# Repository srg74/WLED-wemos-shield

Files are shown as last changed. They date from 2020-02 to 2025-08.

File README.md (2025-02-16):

# WLED wemos shield with [plug-in add-ons](https://github.com/srg74/WLED-wemos-shield/tree/master/resources/Add-ons)








I appreciate your support for my project! 

## Wi-Fi LED shield based on Wemos D1 Mini original or clones, Wemos ESP32 D1 mini, for WLED firmware

- Detailed assembly and option information is [here](https://github.com/srg74/WLED-wemos-shield/wiki)

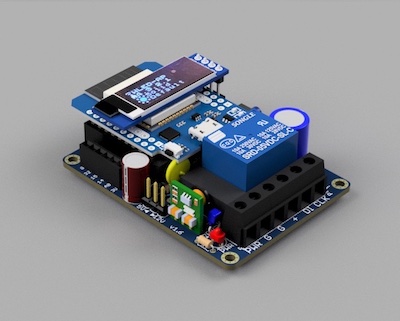
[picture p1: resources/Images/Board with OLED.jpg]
Shield (https://github.com/srg74/WLED-wemos-shield/wiki)


### For changes in design please see [changelog.md](https://github.com/srg74/WLED-wemos-shield/blob/master/Changelog.md)

## PCB ordering

- [Ordering](https://www.pcbway.com/project/shareproject/WLED_wemos_shield.html) - $5 for 10 PCBs very good quality.
- [Sign in and save](https://www.pcbway.com/setinvite.aspx?inviteid=83580) - Helping me to save some money for development.
- [Ready to use fully assembled shield on Tindie](https://www.tindie.com/products/22307/)

## Wi-Fi LED controller with following features

- Very easy to configure for your project;
- Easy to solder components;
- Level shifter for reliable data signal;
- Solder jumpers for flexible configuration;
- Power selector (e.g 5VDC or 12/24VDC);
- Can be configured for 1 (data) wire and 2 (data, clock) wire addressable LED strips;
- Analog and Digital input for sound reactive compatability;
- Button option on board;
- Relay for power saving feature (without disconnecting power from LED strip it still consumes current even if none of the LEDs are lit);
- Auxilary power for additional relay or other 5VDC powered devices;
- I2C connector for OLED display or other devices that might be integrated in a feature;
- I2S connectivity for ESP32 boards;
- Optional IR reciever;
- Optional Dallas temperature sensor;
- Optional I2C sensors;
- Components on board for 4 or 3 pin PWM fan circuit.

## Firmware

### Ready to use bin files

- [@Aircookie repo firmware builds](https://github.com/srg74/WLED-wemos-shield/tree/master/resources/Firmware/%40Aircoookie) - Original WLED repository bin files for various configurations
- [@blazoncek fork firmware builds](https://github.com/srg74/WLED-wemos-shield/tree/master/resources/Firmware/%40blazoncek) - Custom development bin files for various configurations
- [@Atuline fork firmware builds](https://github.com/srg74/WLED-wemos-shield/tree/master/resources/Firmware/%40Atuline) - Sound reactive bin files for various configurations
- [@Moonmodules fork firmware builds](https://github.com/srg74/WLED-wemos-shield/tree/master/resources/Firmware/%40MoonModules) - Advanced sound reactive bin files for various configurations

### Resources used for bin files compiling

- [WLED repository](https://github.com/wled-dev/WLED) - Aircoookie original WLED repository
- [Atuline WLED fork](https://github.com/atuline/WLED) - Audio reactive WLED fork
- [MoonModules WLED fork](https://github.com/MoonModules/WLED) - Enhenced Audio reactive WLED fork 
- [WLED dev repository](https://github.com/blazoncek/WLED) - Blazoncek advanced development WLED fork

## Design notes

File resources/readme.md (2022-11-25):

# PCB ordering

- [Ordering](https://www.pcbway.com/project/shareproject/WLED_wemos_shield.html) - $5 for 10 PCBs in no time :) Parts list in BOM.

## Shield PCBs and schematic

## PCB

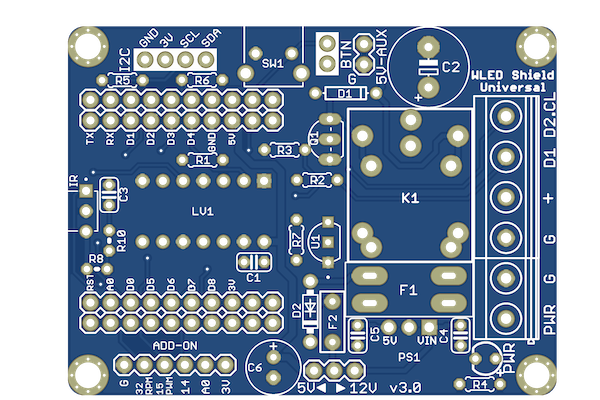
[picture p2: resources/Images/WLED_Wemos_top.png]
PCB


## Schematic

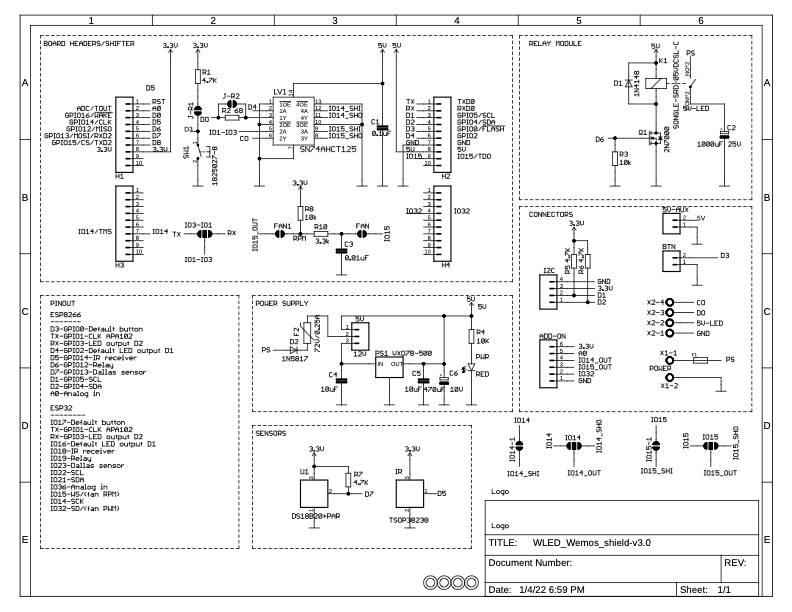
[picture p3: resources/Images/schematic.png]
Schematic


## Parts

- [BOM](https://github.com/srg74/WLED-wemos-shield/blob/master/resources/BOM/BOM_v2.1.pdf) - Bill of materials in PDF format.
- [BOM](https://github.com/srg74/WLED-wemos-shield/blob/master/resources/BOM/BOM_v2.1.xlsx) - Bill of materials in XLSX format.
- [BOM](https://github.com/srg74/WLED-wemos-shield/blob/master/resources/BOM/BOM_v2.1_LCSC.xlsx) - Bill of materials for ordering at LCSC.com.
- [Digikey part list](https://github.com/srg74/WLED-wemos-shield/blob/master/resources/BOM/BOM_Digi-key_v2.1.csv) - BOM file that you can upload to Digikey website for order.

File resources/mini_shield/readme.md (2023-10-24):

# WLED Wemos mini shield

- [ESP8266 and ESP32 firmware](https://github.com/srg74/WLED-wemos-shield/tree/master/resources/Firmware/WLED_wemos_shield) -  Aircookie official.
- [ESP8266 and ESP32 firmware](https://github.com/srg74/WLED-wemos-shield/tree/master/resources/Firmware/Sound_reactive) - Sound reactive WLED repository from [Andrew Tuline](https://github.com/atuline/WLED).
- [ESP8266 and ESP32 firmware](https://github.com/srg74/WLED-wemos-shield/tree/master/resources/experimental) - Advanced experimental WLED repository from [Blazoncek](https://github.com/blazoncek/WLED).
- [Connection guide](https://github.com/srg74/WLED-wemos-shield/blob/master/resources/mini_shield/mini_connection_guide_v1.2.pdf) - Connection guide for WS281X strips and clocked APA102.
- [Pinout for standart mini shield](https://github.com/srg74/WLED-wemos-shield/blob/master/resources/mini_shield/mini_shield_v1.2_pinout.pdf)
- [Pinout for AUX mini shield](https://github.com/srg74/WLED-wemos-shield/blob/master/resources/mini_shield/aux-shield.md)
- [Recommended 3D printed enclosure](https://www.thingiverse.com/thing:4965917) - design by @HarryBaas

***
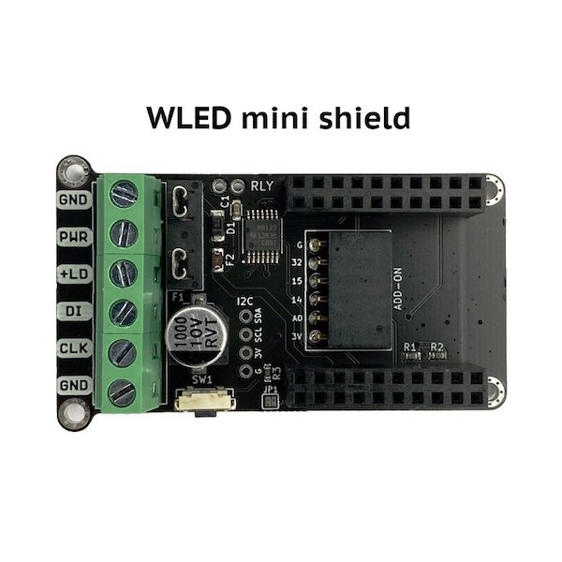
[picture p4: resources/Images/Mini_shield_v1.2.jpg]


***
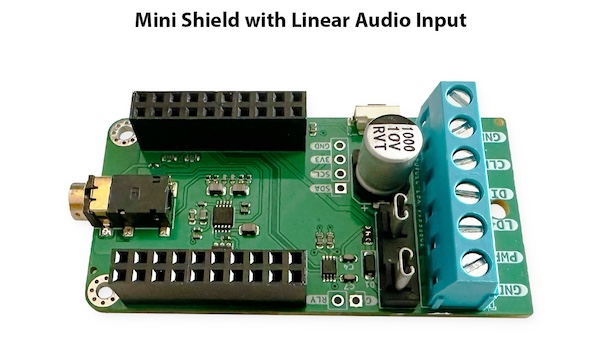
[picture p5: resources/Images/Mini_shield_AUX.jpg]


- [Pinout for AUX mini shield](https://github.com/srg74/WLED-wemos-shield/blob/master/resources/mini_shield/aux-shield.md)

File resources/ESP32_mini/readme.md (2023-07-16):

# ESP32 mini dev board

[All docs moved to](https://github.com/srg74/ESP32-mini-SerKo) separate GitHub repo

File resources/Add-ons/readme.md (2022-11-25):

# Available add-ons

## [Linear audio input add-on plug-in board](#1linear-audio-input-add-on-plug-in-board)

## [Digital microphone ICS-43434 add-on plug-in board](#2digital-microphone-ics-43434-add-on-plug-in-board)

## [Digital input/output screw terminal add-on plug-in board](#3-digital-inputoutput-screw-terminal-add-on-plug-in-board)

### [1]Linear audio input add-on plug-in board

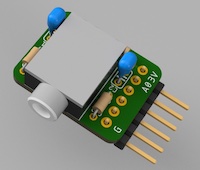
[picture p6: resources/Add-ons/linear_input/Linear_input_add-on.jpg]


- [Order PCB](https://www.pcbway.com/project/shareproject/Audio_input_for_shield_v1_5.html)
- [Schematic](https://github.com/srg74/WLED-wemos-shield/blob/master/resources/Add-ons/linear_input/Sound_reactive_add-on.pdf)
- [Parts](https://github.com/srg74/WLED-wemos-shield/blob/master/resources/Add-ons/linear_input/BOM.pdf)
- [All credits and references for circuits. Thanks to atuline and his team for the Sound reactive fork](https://github.com/atuline/WLED)

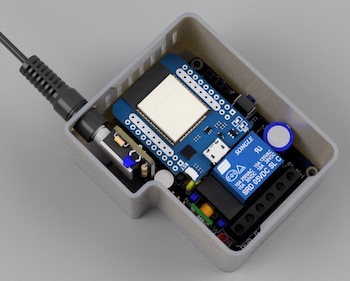
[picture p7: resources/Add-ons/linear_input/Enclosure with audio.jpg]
Linear in


### [2]Digital microphone ICS-43434 add-on plug-in board

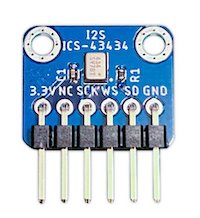
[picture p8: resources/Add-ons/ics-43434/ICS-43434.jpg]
ICS43434




- [Schematic](https://github.com/srg74/WLED-wemos-shield/blob/master/resources/Add-ons/ics-43434/ics43434_shield.jpg)

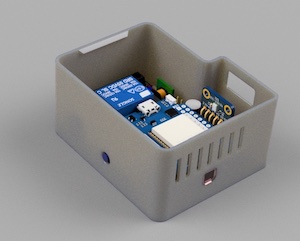
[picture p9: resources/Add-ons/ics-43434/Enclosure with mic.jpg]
Enclosure with mic


### [3] Digital input/output screw terminal add-on plug-in board

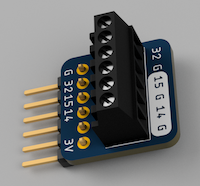
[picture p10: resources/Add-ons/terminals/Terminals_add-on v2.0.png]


- [Order PCB](https://www.pcbway.com/project/shareproject/Audio_input_for_shield_v1_5.html)
- [Schematic](https://github.com/srg74/WLED-wemos-shield/blob/master/resources/Add-ons/terminals/Terminals_add-on.pdf)
- [Parts](https://github.com/srg74/WLED-wemos-shield/blob/master/resources/Add-ons/terminals/BOM.xlsx)

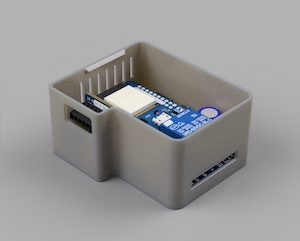
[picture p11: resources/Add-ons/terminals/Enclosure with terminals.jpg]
Screw terminals


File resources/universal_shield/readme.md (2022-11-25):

# Universal shield black v3.0

- [Shield pinout](https://github.com/srg74/WLED-wemos-shield/blob/master/resources/Images/wiki/Wemos_shield_pinout.pdf)

## Shield PCBs and schematic

## PCB

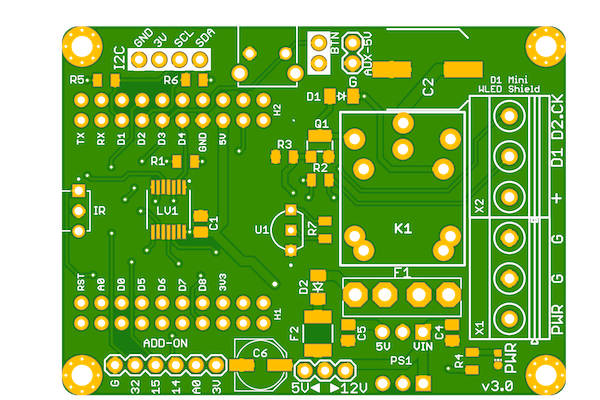
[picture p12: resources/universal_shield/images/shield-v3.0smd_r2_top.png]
PCB top


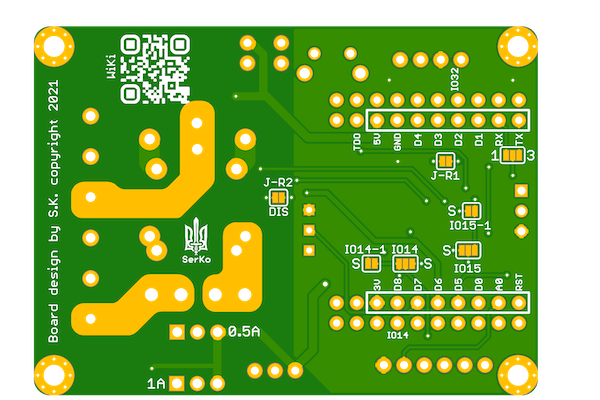
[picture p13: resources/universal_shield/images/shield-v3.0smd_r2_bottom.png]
PCB bottom


## Solder jumpers

- By default shield is preconfigured for use with digital microphone(IO14 and IO15 not shifted);
- Jumpers have to be soldered according to chosen configuration:
- IO1-IO3 - Lets you choose D2 output, GPIO1 or GPIO3;
- IO15 (ESP32 only)- Lets you choose if your output 15 is shifted or not (side marked "S" is shifted);
- IO15-1 (ESP32 only) - Must be soldered if output 15 is shifted;
- IO14 (ESP32 only) - Lets you choose if your output 14 is shifted or not (side marked "S" is shifted);
- IO14-1 (ESP32 only) - Must be soldered if  output 14 is shifted;
- J-R2 - If soldered, bypasses resistor R2;
- J-R1 - Soldered if resistor R1 must be used;

## Schematic

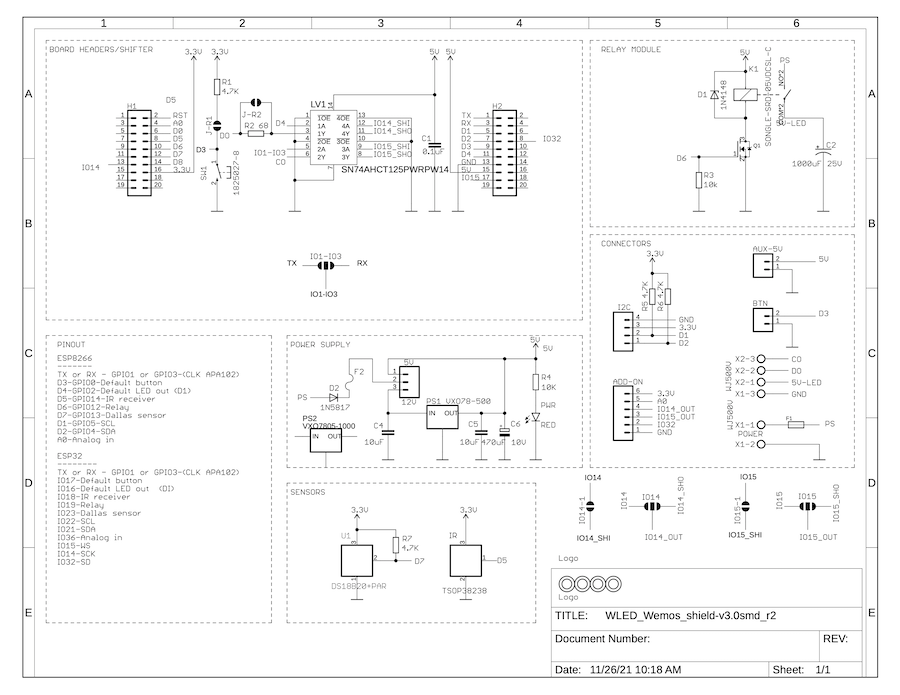
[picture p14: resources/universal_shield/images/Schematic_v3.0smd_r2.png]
Schematic


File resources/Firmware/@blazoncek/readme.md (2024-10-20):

# Development fork @blazoncek

- [v0.15.0-b6 builds](https://github.com/srg74/WLED-wemos-shield/tree/master/resources/Firmware/@blazoncek/latest) - v0.15.0-b6 build 2410200

```text
# Example for a build
[env:esp32_Dallas_sensor_PWM_fan_display_rotary_ambient_light_sensor_sound_mods]
board = esp32dev
platform = espressif32@3.5
upload_speed = 460800
monitor_speed = 115200
;upload_protocol = espota
# exchange for your WLED IP
;upload_port = "10.0.0.94"
build_unflags = ${common.build_unflags}
build_flags = ${common.build_flags_esp32}
  -D WLED_DISABLE_BLYNK
  -D WLED_DISABLE_CRONIXIE
  -D WLED_DISABLE_HUESYNC
  -D WLED_DISABLE_LOXONE
# Enable Ethernet shield
;  -D WLED_USE_ETHERNET
# Pins assigment and pixel count
  -D BTNPIN=0
  -D LEDPIN=2 # Single pin
;  -D DATA_PINS=1,2 # Multiple pins
;  -D PIXEL_COUNTS=150,150,150,150 # Pixel count assigment
  -D IRPIN=-1
  -D RLYPIN=16
# User mods
  # Dallas temperature sensor mod
  -D USERMOD_DALLASTEMPERATURE
  -D TEMPERATURE_PIN=4
  # Display mod
  # I2C display section
  -D USERMOD_FOUR_LINE_DISPLAY
  -D USE_ALT_DISPlAY
  -D FLD_PIN_SCL=22
  -D FLD_PIN_SDA=21
  -D FLD_TYPE=SH1106
;  -D FLD_TYPE=SSD1306
  # SPI display section
  ; -DFLD_SPI_DEFAULT
  ; -D FLD_TYPE=SSD1306_SPI64
  ; -D FLD_PIN_CLOCKSPI=14
  ; -D FLD_PIN_DATASPI=13
  ; -D FLD_PIN_DC=26
  ; -D FLD_PIN_CS=15
  ; -D FLD_PIN_RESET=27
  # Rotary encoder mod
  -D USERMOD_ROTARY_ENCODER_UI
  -D ENCODER_DT_PIN=18
  -D ENCODER_CLK_PIN=19
  -D ENCODER_SW_PIN=17
  # Multirelay mod
  ; -D USERMOD_MULTI_RELAY  # 12, 23, 22 & 21
  # PWM Fan mod
  -D USERMOD_PWM_FAN
  -D PWM_PIN=32
  -D TACHO_PIN=33
  # Ambient light sensor BH1750
  -D USERMOD_BH1750
  -D USERMOD_BH1750_FIRST_MEASUREMENT_AT=30000
  -D USERMOD_BH1750_MAX_MEASUREMENT_INTERVAL=60000
;  -D USERMOD_BH1750_MIN_MEASUREMENT_INTERVAL=10000
;  -D USERMOD_BH1750_OFFSET_VALUE=2
  # Sound reactive usermod
  -D USERMOD_AUDIOREACTIVE
;  -D WLED_DEBUG
  -UWLED_USE_MY_CONFIG
lib_deps = ${esp32.lib_deps}
  U8g2@~2.32.15 # Uncoment for display mod
  paulstoffregen/OneWire@~2.3.6 # Uncoment for temperature mod
  claws/BH1750 @ ^1.3.0 # Uncoment for light sensor mod
  https://github.com/blazoncek/arduinoFFT.git
board_build.partitions = ${esp32.default_partitions}
```

## 🔴 Please, test latest firmware and report any issue to WLED Discord. Help highly anticipated and appreciated! 🔴

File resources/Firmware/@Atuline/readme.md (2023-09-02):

# Audio reactive fork firmware @Atuline

[ESP32 Audio reactive firmware](https://github.com/srg74/WLED-wemos-shield/tree/master/resources/Firmware/@Atuline/latest) - 0.13.4 build 2309020

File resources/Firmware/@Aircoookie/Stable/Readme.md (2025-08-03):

# WLED PlatformIO Builds

This project supports multiple hardware targets and configurations. Below is a summary of the actively defined builds:

---

## Shields Builds

### esp01_1m_full_shield

- **Target:** ESP01 shield (1MB flash)
- **Features:** Minimal build for ESP01 shield, disables several features to fit in 1MB.

### esp8266_mini_shield_minimum

- **Target:** D1 mini board (4MB)
- **Features:** Minimal build for mini shield, disables some features for space.

### esp32_mini_shield_minimum_4mb

- **Target:** ESP32 mini board (4MB)
- **Features:** Minimal build for ESP32 mini shield, disables some features for space.

### esp32_mini_shield_minimum_16mb

- **Target:** ESP32 mini board (16MB)
- **Features:** Minimal build for ESP32 mini shield, disables some features for space.

### esp32_mini_shield_aux_16mb

- **Target:** ESP32 mini board (16MB)
- **Features:** Auxiliary build, includes audio reactive usermod.

### esp8266_universal_shield_minimum

- **Target:** D1 mini board (universal shield)
- **Features:** Minimal build for universal shield, disables some features for space.

### esp32_universal_shield_minimum_4mb

- **Target:** ESP32 mini board (4MB, universal shield)
- **Features:** Minimal build for universal shield, disables some features for space.

### esp32_universal_shield_minimum_16mb

- **Target:** ESP32 mini board (16MB, universal shield)
- **Features:** Minimal build for universal shield, disables some features for space.

### esp32_universal_shield_usermods_4mb

- **Target:** ESP32 board (4MB, universal shield)
- **Features:** Usermods build, includes temperature, four_line_display_ALT, rotary encoder, audioreactive.

### esp32_universal_shield_usermods_16mb

- **Target:** ESP32 board (16MB, universal shield)
- **Features:** Usermods build, includes temperature, four_line_display_ALT, rotary encoder, audioreactive.

---

## ESP32 Dev Board Builds

### esp32_devb_Dallas_sensor_PWM_fan_mods_4mb

- **Target:** ESP32 dev board (4MB)
- **Features:** Dallas temperature sensor, PWM fan usermods.

### esp32_devb_Dallas_sensor_PWM_fan_mods_16mb

- **Target:** ESP32 dev board (16MB)
- **Features:** Dallas temperature sensor, PWM fan usermods.

### esp32_devb_SHT_sensor_PWM_fan_mods_16mb

- **Target:** ESP32 dev board (16MB)
- **Features:** SHT temperature sensor, PWM fan usermods.

### esp32_devb_4ch_fan_display_rotary_relays

- **Target:** ESP32 dev board
- **Features:** PWM fan, temperature, four_line_display_ALT, rotary encoder, multi relay usermods.

---

## ESP32-pico-D4 Board Builds

### esp32_pico_board

- **Target:** ESP32-pico-D4 board
- **Features:** Audio reactive usermod.

### esp32_pico_v3_02

- **Target:** ESP32-pico-v3-02 board
- **Features:** 8MB flash, disables brownout detector.

---

## Manufacturer Hacked Controllers

### sp501e_2mb

- **Target:** ESP8266 2MB board (SP501E)
- **Features:** Disables several features for space, supports up to 3 virtual busses.

### sp511e_2mb

- **Target:** ESP8266 2MB board (SP511E)
- **Features:** Disables several features for space, supports up to 3 virtual busses.

---

## Users Requested/Test Builds

### esp8266_debug

- **Target:** ESP8266 (D1 mini)
- **Features:** Debug build, disables some features, enables debug output.

### esp32_debug

- **Target:** ESP32 dev board
- **Features:** Debug build, includes audioreactive usermod, enables debug output.

### esp8266_dmx

- **Target:** ESP8266 (D1 mini)
- **Features:** DMX support enabled.

### esp8266_PIRmod

- **Target:** ESP8266 (D1 mini)
- **Features:** PIR switch usermod.

### esp8266_staircase_mod

- **Target:** ESP8266 (D1 mini)
- **Features:** Animated staircase usermod, disables several features.

### esp8266_display_rotary

- **Target:** ESP8266 (D1 mini)
- **Features:** Four line display and rotary encoder usermods.

### esp8266_dallas_mod

- **Target:** ESP8266 (D1 mini)
- **Features:** Dallas temperature sensor usermod, disables several features.

### esp32_PIRmod

- **Target:** ESP32 dev board
- **Features:** PIR switch usermod.

### esp32_staircase_mod

- **Target:** ESP32 dev board
- **Features:** Animated staircase usermod.

### esp32_ethernet

- **Target:** ESP32 dev board
- **Features:** Ethernet support enabled, disables several features.

### esp32_dmx

- **Target:** ESP32 dev board
- **Features:** DMX support enabled.

### esp32_bme280

- **Target:** ESP32 dev board
- **Features:** BME280 sensor and four line display usermods.

### esp32_display_rotary_encoder_battery_stat

- **Target:** ESP32 dev board
- **Features:** Four line display and rotary encoder usermods.

### esp32s2_saola_1

- **Target:** ESP32-S2 Saola board
- **Features:** Experimental build for ESP32-S2.

### esp32s3dev_8MB

- **Target:** ESP32-S3 dev board (8MB)
- **Features:** Audio reactive usermod, new FFT, S3-specific settings.

### esp32_stamp5_c3

- **Target:** ESP32-C3 devkit
- **Features:** Audio reactive usermod, SQUELCH and GAIN settings for ICS-4343x.

---

## Notes

- Each build can be selected by specifying the corresponding environment in PlatformIO.
- For custom builds, refer to the comments and usermod documentation for additional configuration options.

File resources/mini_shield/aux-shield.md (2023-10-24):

# AUX mini shield configuration

```    -D LEDPIN=16 #  2nd output or LED CLK GPIO 17
    -D RLYPIN=-1 # If relay connected GPIO 19
    -D BTNPIN=5 # Button GPIO 5
    -D IRPIN=-1 # IR pin disabled
    -D SR_DMTYPE=4 # Type of audio processor
    -D MCLK_PIN=0 # Clock pin
    -D I2S_SDPIN=26
    -D I2S_WSPIN=25
    -D I2S_CKPIN=27
```

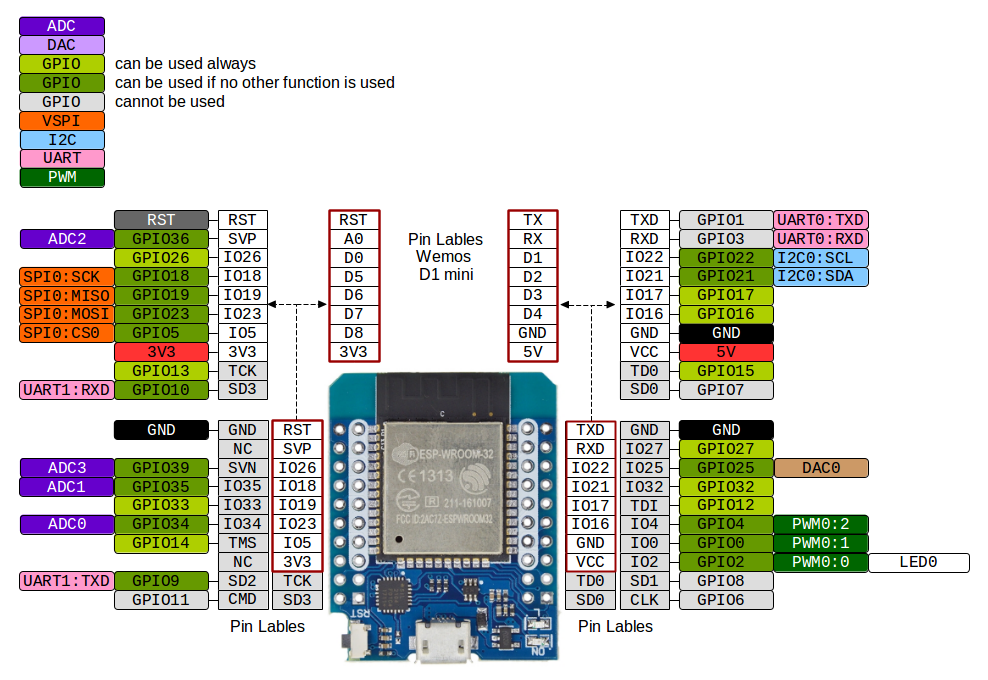
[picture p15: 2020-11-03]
resources/Images/MH-ET_LIVE_D1_mini_ESP32_pinout.png

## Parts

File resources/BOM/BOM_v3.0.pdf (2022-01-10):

### WLED_Wemos_shield_Digikey

WLED Wemos shield BOM

Name | Value | Manufacturer | Digikey | MPN | QTY
R3, R4, R8 | 10kOhm | Stackpole Electronics Inc | S10KQCT-ND | CFM14JT10K0 | 3
R1, R5, R6, R7 | 4.7kOhm | Stackpole Electronics Inc | S4.7KQCT-ND | CFM14JT4K70 | 4
R2 | 56Ohm | Stackpole Electronics Inc | S56QCT-ND | CFM14JT56R0 | 1
R10 | 3.3kOhm | Stackpole Electronics Inc | S3.3KQCT-ND | CFM14JT3K30 | 1
C1 | 0.1uF | Kemet | 399-4151-ND | C315C104M5U5TA | 1
C4, C5 | 10uF | TDK Corporation | 445-8262-ND | FK11X7R1E106M | 2
C3 | 0.01uF | Hemet | 399-C316C103M5U5TA-ND | C316C103M5U5TA | 1
C6 | 470uF 10V | Würth Elektronik | 732-8708-1-ND | 860010273011 | 1
C2 | 1000uF 25V | Nichicon | 493-1065-ND | UVR1E102MPD | 1
Q1 | 2N7000 | ON Semiconductor | 2N7000FS-ND | 2N7000 | 1
D1 | 1N4148 | Vishay Diodes | 1N4148-P-TAPGICT-ND | 1N4148-P-TAP | 1
D2 | 1N5817 | Micro Commercial Co | 1N5817-TPCT-ND | 1N5817-TP | 1
U1 | DS18B20 | Maxim Integrated | DS18B20+-ND | DS18B20+ | 1
F1 | 3568 | Keystone Electronics | 36-3568-ND | 3568 | 1
F2 | 16V 900mA | Littelfuse Inc. | RUSBF090-2HFCT-ND | RUSBF090-2 | 1
LV1 | SN74AHCT125 | Texas Instruments | 296-4655-5-ND | SN74AHCT125N | 1
K1 | SRD-05VDCSL-C | Songle | Amazon, Aliexpress | SRD-05VDCSL-C | 1
K1 alternate | ORWH-SH-105D1F,000 | TE Connectivity Potter | PB2032-ND | ORWH-SH-105D1F,000 | 1
PS1 (jumper select) | VXO7805-500 | CUI Inc. | 102-4249-ND | VXO7805-500 | 1
X1 | TERM BLK 2P SIDE ENT 5.08MM PCB | Molex | WM4393-ND | 398800302 | 1
X2 | TERM BLK 4P SIDE ENT 5.08MM PCB | Molex | WM13972-ND | 398800304 | 1
H1, H2 | CONN HDR 20POS 0.1 GOLD PCB | Sullins Connector Solutions | S6106-ND | PPPC102LFBN-RC | 2
I2C | CONN HDR 4POS 0.1 GOLD PCB | Sullins Connector Solutions | S7037-ND | PPPC041LFBN-RC | 1
SOUND | CONN HDR 6POS 0.1 GOLD PCB | Sullins Connector Solutions | S7039-ND | PPPC061LFBN-RC | 1
Headers | CONN HEADER VERT 20POS 2.54MM | Harwin Inc. | 952-3306-ND | M20-9992045 | 1
Jumper | CONN JUMPER SHORTING GOLD | Sullins Connector Solutions | S9001-ND | SPC02SYAN | 1
SW1 | SWITCH TACTILE | TE Connectivity | 450-1657-ND | 1825027-8 | 1
IR | SENSOR REMOTE REC 38.0KHZ 45M | Vishay Semiconductor | TSOP38238 | TSOP38238 | 1
FUSE | Mini fuse is depend on current rating of your setup. Kit https://www.amazon.com/CrocSee-250-Pieces-Assortment-Replacement/dp/B0895PV8S2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 (https://www.amazon.com/CrocSee-250-Pieces-Assortment-Replacement/dp/B0895PV8S2)
Power indicator LED | https://www.amazon.com/1-8mm-2mm-Round-Top-Red/dp/B017TR9ZDY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

1

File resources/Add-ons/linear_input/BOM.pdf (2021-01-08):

### WLED_Wemos_add_on_Digikey

WLED Wemos shield BOM

Name | Value | Manufacturer | Digikey | MPN | QTY
R1, R2 | 680Ohm | Stackpole Electronics Inc | S680QCT-ND | CFM14JT680R | 2
R3, R4 | 1mOhm | Stackpole Electronics Inc | S1MQCT-ND | CFM14JT1M00 | 2
C1, C2 | 0.1uF | Kemet | 399-4151-ND | C315C104M5U5TA | 2
Audio jack | 3.50mm - Headphone Phone Jack | Harwin Inc. | CP1-3513N-ND | SJ1-3513N | 1
Connector | Header Right Angle 6 pos | Harwin Inc. | 952-2247-ND | M20-9960645 | 1

1

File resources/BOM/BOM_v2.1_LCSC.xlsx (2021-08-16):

WLED_Wemos_shield_LCSC.com
WLED Wemos shield BOM
Name | Value | Manufacturer | LCSC | MPN | QTY
R3, R4 | 10kOhm | UNI-ROYAL | C58673 | MFR0W8F1002A50 | 2
R1, R5, R6, R7 | 4.7kOhm | UNI-ROYAL | C58678 | MFR0W8F4701A50 | 4
R2 | 36Ohm | VO | C337034 | CR1/8W ±5% 36Ω STB5 | 1
C1 | 0.1uF | FH | C154503 | CT4-0805Y104M500F1 | 1
C4, C5 | 10uF | Murata | C162684 | RDEC71H106K3K1H03B | 2
C6 | 470uF 10V | Samwha Capacitor | C160618 | RD1A477M6L011PC | 1
C2 | 1000uF 25V | CX | C44595 | KM108M025G20RR0VH2FP0 | 1
Q1 | 2N7000 | Changjiang Electronics Tech | C9114 | 2N7000 | 1
D1 | 1N4148 | ST(Semtech) | C14538 | 1N4148 | 1
D2 | 1N5817 | Diodes incorporated | C507852 | 1N5817-T | 1
U1 | DS18B20 | UMW | C376006 | DS18B20 | 1
F1 | 3568 | Keystone Electronics | 36-3568-ND | 3568 | 1
F2 | 30V 0.5A | TECHFUSE | C2833617 | R30-050 | 1
LV1 | SN74AHCT125 | Texas Instruments | C354152 | SN74AHCT125N | 1
K1 | SRD-05VDCSL-C | Songle | C35449 | SRD-05VDC-SL-C | 1
PS1 (jumper select) | K78L05-500R3 | MORNSUN | C115916 | K78L05-500R3 | 1
X1, X2 | TERM GRN 6P SIDE ENT 5.0MM PCB |  | C8379 | WJ126V-5.0-6P | 1
H1, H2 | CONN HDR 20POS 0.1 GOLD PCB | Ningbo | C30867 | C30867 | 2
I2C | CONN HDR 4POS 0.1 GOLD PCB | CJT | C225501 | A2541HWV-4P | 1
SOUND | CONN HDR 6POS 0.1 GOLD PCB | BOOMELE | C40877 | C40877 | 1
Headers | CONN HEADER VERT 40POS 2.54MM | JILN | C429959 | 12251140CNG0S115001 | 1
Jumper | 2 position jumper | Multiple sources |  |  | 1
SW1 | SWITCH TACTILE | Bright | C354960 | TSA067G80-250 | 1
IR | SENSOR REMOTE REC 38.0KHZ 45M | Vishay Semiconductor | C141632 | TSOP38238 | 1
Power indicator LED | Indicator LED red | HONGLITRONIC | C568936 | HL-304S9AD | 1
FUSE | Mini fuse is depend on current rating of your setup. Kit https://www.amazon.com/CrocSee-250-Pieces-Assortment-Replacement/dp/B0895PV8S2

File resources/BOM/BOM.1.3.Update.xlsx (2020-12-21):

WLED Wemos shield Digikey v1.3
WLED Wemos shield BOM |  |  |  |  |  | Bare Minimum | Switch 12v/5v | Temp Sensor | I2c Sensor BME280 or OLED Display | Button | IR Reciver | Power LED +LED nach wahl
Name | Value | Manufacturer | Digikey | MPN | QTY
R3, R4 | 10kOhm | Stackpole Electronics Inc | S10KQCT-ND | CFM14JT10K0 | 3 | R3 1x |  |  |  |  |  | R4 1x
R2, R5, R6, R7 | 4.7kOhm | Stackpole Electronics Inc | S4.7KQCT-ND | CFM14JT4K70 | 4 |  |  | R7 1x | R5 & R6 2x | ! 1x R2
R8 | 150Ohm | Stackpole Electronics Inc | S150QCT-ND | CFM14JT150R | 1 | 1x
C1 | 0.1uF | Kemet | 399-4151-ND | C315C104M5U5TA | 1 | 1x
C4, C5 | 10uF | TDK Corporation | 445-8262-ND | FK11X7R1E106M | 2 |  | 2x
C6 | 470uF 10V | Würth Elektronik | 732-8708-1-ND | 860010273011 | 1 | 1x
C2 | 1000uF 25V | Nichicon | 493-1065-ND | UVR1E102MPD | 1 | 1x
Q1 | 2N7000 | ON Semiconductor | 2N7000FS-ND | 2N7000 | 1 | 1x
D1 | 1N4148 | Vishay Diodes | 1N4148-P-TAPGICT-ND | 1N4148-P-TAP | 1 | 1x
D2 | 1N5817 | Micro Commercial Co | 1N5817-TPCT-ND | 1N5817-TP | 1 | 1x
U1 | DS18B20 | Maxim Integrated | DS18B20+-ND | DS18B20+ | 1 |  |  | 1x
F1 | 3568 | Keystone Electronics | 36-3568-ND | 3568 | 1 | 1x
F2 | 16V 900mA | Littelfuse Inc. | RUSBF090-2HFCT-ND | RUSBF090-2 | 1 | 1x
LV1 | SN74AHCT125 | Texas Instruments | 296-4655-5-ND | SN74AHCT125N | 1 | 1x
K1 | SRD-05VDCSL-C | Songle | Amazon, Aliexpress | SRD-05VDCSL-C | 1
K1 alternate | ORWH-SH-105D1F,000 | TE Connectivity Potter | PB2032-ND | ORWH-SH-105D1F,000 | 1 | 1x
PS1 (jumper select) | VXO7805-500 | CUI Inc. | 102-4249-ND | VXO7805-500 | 1 |  | 1x
X1 | TERM BLK 2P SIDE ENT 5.08MM PCB | Molex | WM4393-ND | 398800302 | 1 | 1x
X2 | TERM BLK 4P SIDE ENT 5.08MM PCB | Molex | WM13972-ND | 398800304 | 1 | 1x
H1, H2 | CONN HDR 8POS 0.1 GOLD PCB | Sullins Connector Solutions | S7041-ND | PPPC081LFBN-RC | 2 | 2x Inkl. On Esp board
Headers | CONN HEADER VERT 20POS 2.54MM | Harwin Inc. | 952-3306-ND | M20-9992045 | 1 | 1x 2pos | 3Pos statt 2Pos
Jumper | CONN JUMPER SHORTING GOLD | Sullins Connector Solutions | S9001-ND | SPC02SYAN | 1 | 1x
SW1 | SWITCH TACTILE | TE Connectivity | 450-1657-ND | 1825027-8 | 1 |  |  |  |  | 1x
H3 (for I2c) | CONN HDR 4POS 0.1 GOLD PCB | Sullins Connector Solutions | S7037-ND | PPPC041LFBN-RC | 1 |  |  |  | 1x
IR Modul |  |  |  | KY-022 | 1 |  |  |  |  |  | 1x
IR Modul (Alternate) | SENSOR REMOTE REC 38.0KHZ 45M | Vishay Semiconductor Opto Division | 751-1227-ND | TSOP38238 | 1 |  |  |  |  |  | 1x

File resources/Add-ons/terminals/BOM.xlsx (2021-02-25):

WLED_Wemos_add_on_Digikey
Terminals add-on BOM
Name | Value | Manufacturer | Digikey | MPN | QTY
Terminal connector | TERM BLK 6P 2.54mm | TE Connectivity | A98337-ND | 282834-6 | 1
Connector | Header Right Angle 6 pos | Harwin Inc. | 952-2247-ND | M20-9960645 | 1

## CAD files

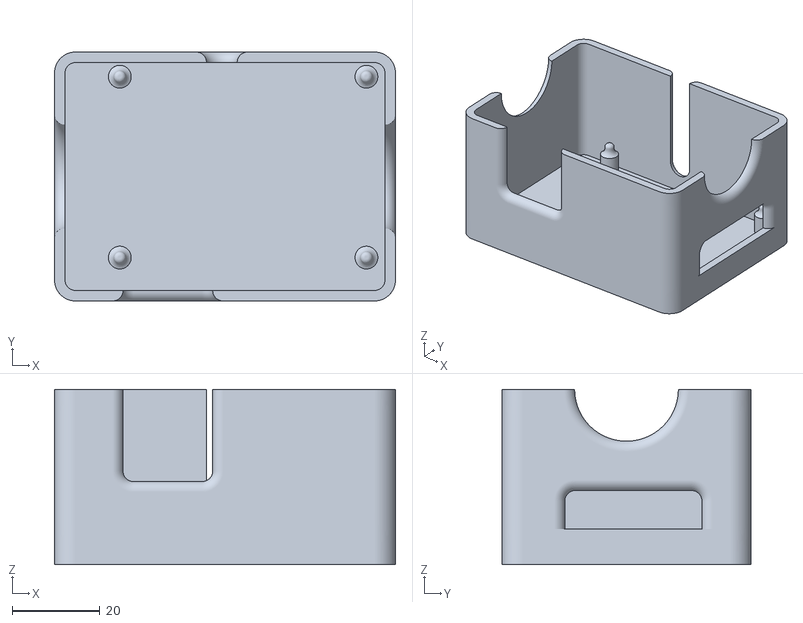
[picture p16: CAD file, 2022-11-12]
resources/universal_shield/enclosure/@RainerUnflug/BOTTOM_V7_SR-WLED-Shield_Sergs-Board-V3_Mic_White.stl
77.8 x 56.8 x 40.0

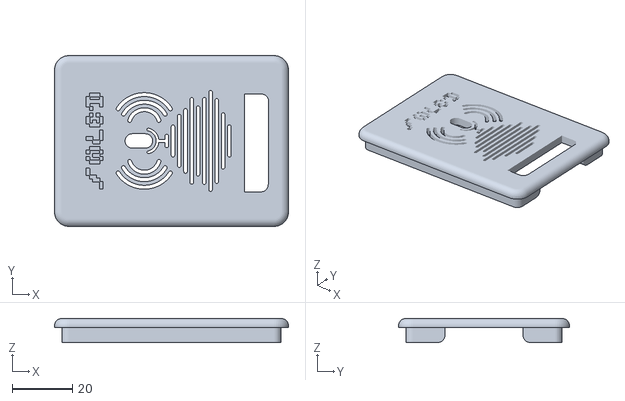
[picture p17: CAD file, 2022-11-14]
resources/universal_shield/enclosure/@RainerUnfug/COVER_V7_SR-WLED-Shield_Sergs-Board-V3_Mic.stl
77.8 x 56.8 x 8.00

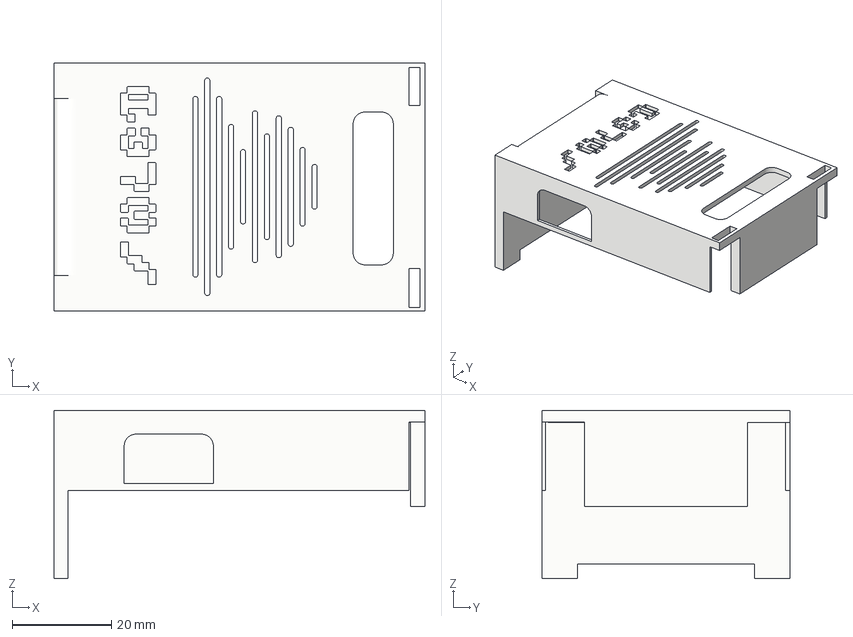
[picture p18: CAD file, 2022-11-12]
resources/universal_shield/enclosure/@RainerUnflug/TOP_SR-WLED_Shield_SergsBoard_Mic3-0_white.3mf
74.9 x 50.1 x 34.0 mm

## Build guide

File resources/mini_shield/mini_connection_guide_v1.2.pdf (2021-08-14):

WLED Wemos connections

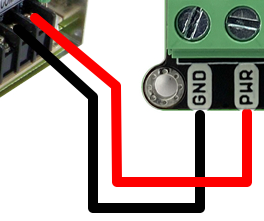
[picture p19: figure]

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
WLED Wemos connections

A

PA-1

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
WLED Wemos connections

WLED Wemos connections

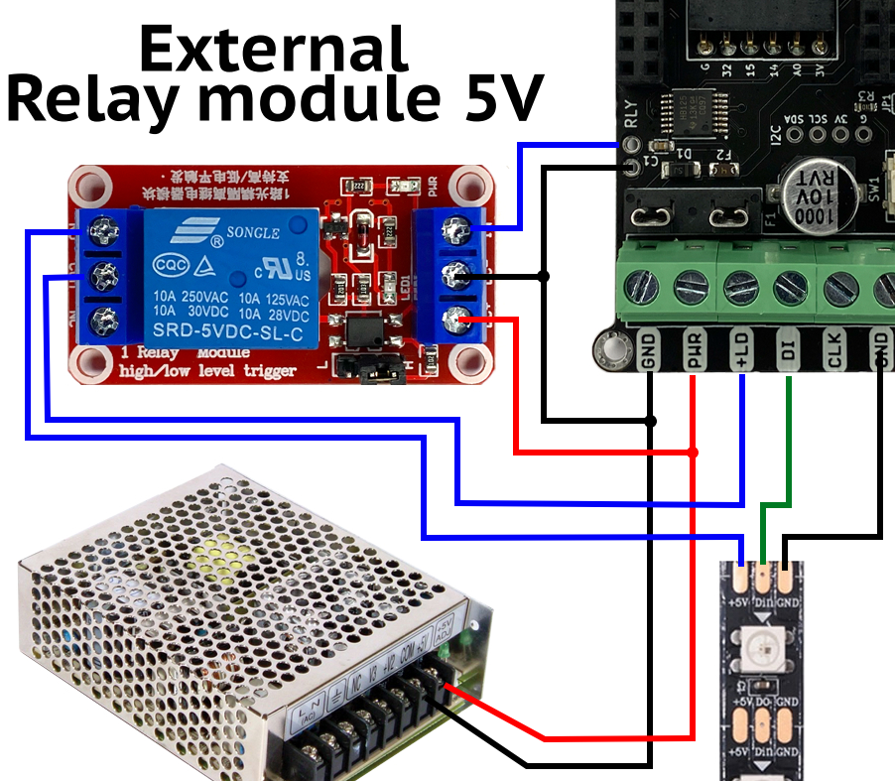
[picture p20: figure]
External Relay module 5V

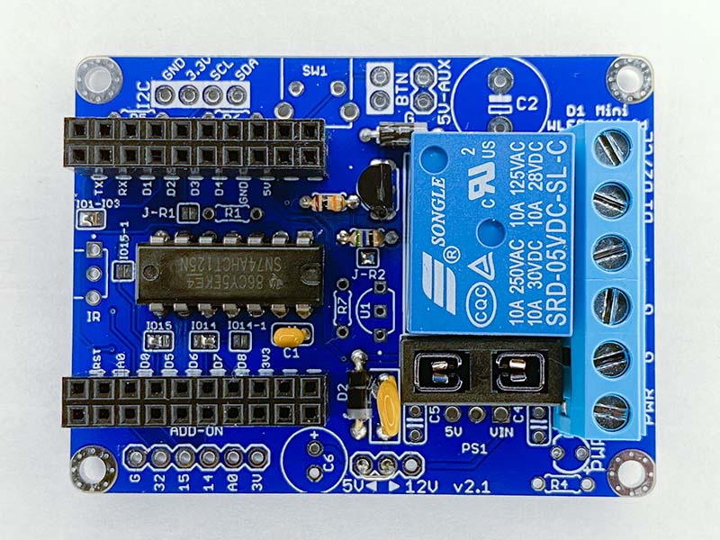
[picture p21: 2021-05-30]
resources/Images/wiki/step4.jpg

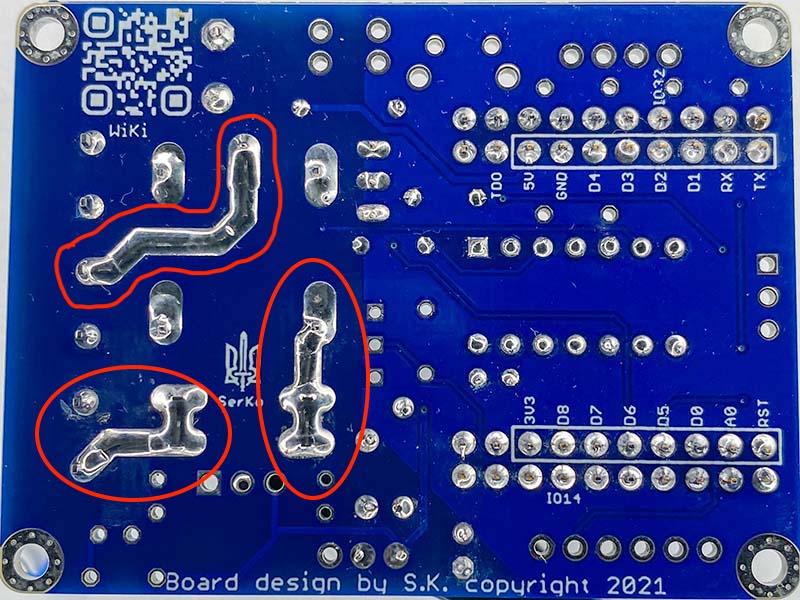
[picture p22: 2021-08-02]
resources/Images/wiki/step6_1.jpg

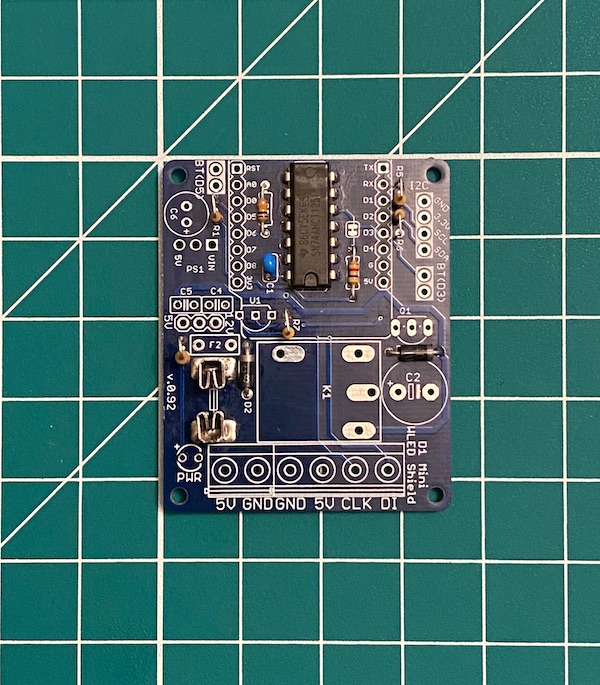
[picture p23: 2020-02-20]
resources/Images/Assembly_1.jpg

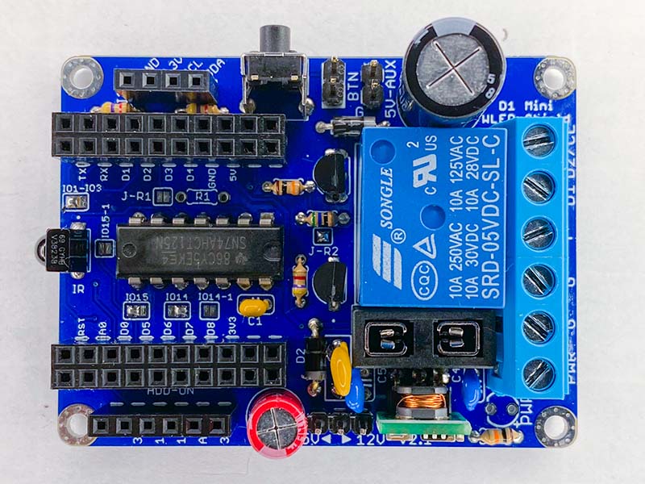
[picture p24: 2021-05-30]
resources/Images/wiki/fully-assembled.jpg

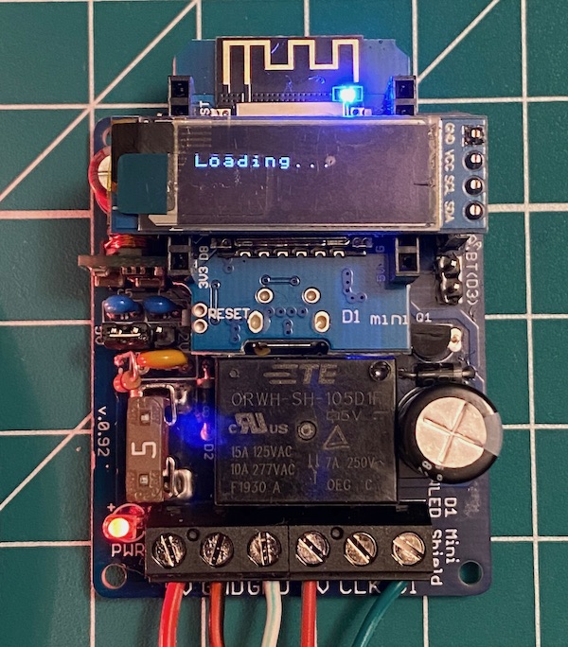
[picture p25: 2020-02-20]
resources/Images/Assembly_7.jpg

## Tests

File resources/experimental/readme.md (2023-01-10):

# Beta for testing. Multiple usermods

## WLED ESP flasher
- [2210130 build](https://github.com/srg74/WLED-wemos-shield/tree/master/resources/Firmware/WLED_%20ESP_Flasher) - for MacOS, Windows.

## GUI configurable usermods

- [v0.14.0-bl0 builds](https://github.com/srg74/WLED-wemos-shield/tree/master/resources/experimental/Firmware) - v0.14.0-bl0 build 2212091

- [v0.14.0-b1.15 builds audio reactive](https://github.com/srg74/WLED-wemos-shield/tree/master/resources/experimental/Firmware/AudioReactive) - ESP32 only v0.14.0-b1.15 build 2301101

- [v0.14.0-bl0 builds ESP32-S2, S3, C3](https://github.com/srg74/WLED-wemos-shield/tree/master/resources/experimental/Firmware/ESP32-S2,S3,C3) - v0.14.0-bl0 build 2212091

All builds are from https://github.com/blazoncek/WLED/tree/segment-api with various usermods. Mod name is included in the file name.

```
# Example for a build
[env:esp32_Dallas_sensor_PWM_fan_display_rotary_ambient_light_sensor_sound_mods]
board = esp32dev
platform = espressif32@3.5
upload_speed = 460800
monitor_speed = 115200
;upload_protocol = espota
# exchange for your WLED IP
;upload_port = "10.0.0.94"
build_unflags = ${common.build_unflags}
build_flags = ${common.build_flags_esp32}
  -D WLED_DISABLE_BLYNK
  -D WLED_DISABLE_CRONIXIE
  -D WLED_DISABLE_HUESYNC
  -D WLED_DISABLE_LOXONE
# Enable Ethernet shield
;  -D WLED_USE_ETHERNET
# Pins assigment and pixel count
  -D BTNPIN=0
  -D LEDPIN=2 # Single pin
;  -D DATA_PINS=1,2 # Multiple pins
;  -D PIXEL_COUNTS=150,150,150,150 # Pixel count assigment
  -D IRPIN=-1
  -D RLYPIN=16
# User mods
  # Dallas temperature sensor mod
  -D USERMOD_DALLASTEMPERATURE
  -D TEMPERATURE_PIN=4
  # Display mod
  # I2C display section
  -D USERMOD_FOUR_LINE_DISPLAY
  -D USE_ALT_DISPlAY
  -D FLD_PIN_SCL=22
  -D FLD_PIN_SDA=21
  -D FLD_TYPE=SH1106
;  -D FLD_TYPE=SSD1306
  # SPI display section
  ; -DFLD_SPI_DEFAULT
  ; -D FLD_TYPE=SSD1306_SPI64
  ; -D FLD_PIN_CLOCKSPI=14
  ; -D FLD_PIN_DATASPI=13
  ; -D FLD_PIN_DC=26
  ; -D FLD_PIN_CS=15
  ; -D FLD_PIN_RESET=27
  # Rotary encoder mod
  -D USERMOD_ROTARY_ENCODER_UI
  -D ENCODER_DT_PIN=18
  -D ENCODER_CLK_PIN=19
  -D ENCODER_SW_PIN=17
  # Multirelay mod
  ; -D USERMOD_MULTI_RELAY  # 12, 23, 22 & 21
  # PWM Fan mod
  -D USERMOD_PWM_FAN
  -D PWM_PIN=32
  -D TACHO_PIN=33
  # Ambient light sensor BH1750
  -D USERMOD_BH1750
  -D USERMOD_BH1750_FIRST_MEASUREMENT_AT=30000
  -D USERMOD_BH1750_MAX_MEASUREMENT_INTERVAL=60000
;  -D USERMOD_BH1750_MIN_MEASUREMENT_INTERVAL=10000
;  -D USERMOD_BH1750_OFFSET_VALUE=2
  # Sound reactive usermod
  -D USERMOD_AUDIOREACTIVE
;  -D WLED_DEBUG
  -UWLED_USE_MY_CONFIG
lib_deps = ${esp32.lib_deps}
  U8g2@~2.32.15 # Uncoment for display mod
  paulstoffregen/OneWire@~2.3.6 # Uncoment for temperature mod
  claws/BH1750 @ ^1.3.0 # Uncoment for light sensor mod
  https://github.com/blazoncek/arduinoFFT.git
board_build.partitions = ${esp32.default_partitions}
```

## 🔴 Please, test latest firmware and report any issue to WLED Discord. Help highly anticipated and appreciated! 🔴

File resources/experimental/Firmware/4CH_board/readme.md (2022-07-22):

# [ENV]

```[env:esp32_4ch_fan_display_rotary_relays]
board = esp32dev
platform = espressif32@3.2
board_build.partitions = tools/WLED_ESP32_4MB_1MB_FS.csv
;board_build.partitions = tools/WLED_ESP32_16MB.csv
upload_speed = 460800
monitor_speed = 115200
;upload_protocol = espota
# exchange for your WLED IP
;upload_port = "10.0.0.XX"
build_unflags = ${common.build_unflags}
build_flags = ${common.build_flags_esp32}
  -D BTNPIN=0
  -D LEDPIN=2
  -D RLYPIN=-1
  -D IRPIN=-1
  -D WLED_DISABLE_ALEXA
  -D WLED_DISABLE_BLYNK
  -D WLED_DISABLE_CRONIXIE
  -D WLED_DISABLE_HUESYNC
  -D WLED_DISABLE_LOXONE
  -D USERMOD_DALLASTEMPERATURE
  -D TEMPERATURE_PIN=25
  -D USERMOD_FOUR_LINE_DISPLAY # GPIOs: 14, 13, 15, 26, 27
  -D USE_ALT_DISPlAY
  -D FLD_PIN_CLOCKSPI=14
  -D FLD_PIN_DATASPI=13
  -D FLD_PIN_DC=26
  -D FLD_PIN_CS=15
  -D FLD_PIN_RESET=27
  -D USERMOD_ROTARY_ENCODER_UI
  -D ENCODER_DT_PIN=5
  -D ENCODER_CLK_PIN=18
  -D ENCODER_SW_PIN=19
  -D USERMOD_MULTI_RELAY       # GPIOs: 12, 23, 22 & 21
  -D USERMOD_PWM_FAN           # GPIOs: 32, 33
;  -D DEBUG=1
;  -D WLED_DEBUG
;  -DDEBUG_ESP_WIFI
  -UWLED_USE_MY_CONFIG
lib_deps = ${esp32.lib_deps}
  OneWire@~2.3.6
  U8g2@~2.28.8
```

- build 2207221

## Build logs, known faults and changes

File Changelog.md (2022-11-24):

# Sound reactive board is depricated. All features will be available on Universal WLED Wemos shield as plug-in add-on

## v3.0

- All configuration solder jumpers moved to bottom of the shield for easy access
- Added alternate relay model SRA-05VDC-SL-C 15A nominal

## v2.1

- Added possibility to switch digital out 2 -> clock pin (GPIO1/GPIO3)
- Added header for Auxiliary 5V (requires buck converter upgrade to 1000mA)
- Wiki updated for shields v2.0 and above
- Shield mounting holes are now 3mm

## v2.0

- Added capability to connect up to 4 LED strips with level shifting.
- Added more flexibility with solder-on jumpers.

### Added [terminals add-on](https://github.com/srg74/WLED-wemos-shield/tree/master/resources/Add-ons)

### Added [linear audio input plug-in, and digital ICS-43434 microphone add-on boards](https://github.com/srg74/WLED-wemos-shield/tree/master/resources/Add-ons) for Shield v1.5 and up

### v1.51

- Minor update. Fixed library and gerber file errors.
- Added [WLED firmware v0.11 Build 2012070](https://github.com/srg74/WLED-wemos-shield/tree/master/resources/Firmware/WLED_wemos_shield/v0.11)
- Old builds removed.
- Added board STEP file.

### v1.5

- Exposed additional pins for I2S microphones. :bangbang: ESP32 boards only :bangbang:
- Removed 3 position header labeled AUDIO.
- Added  6 position header labeled SOUND.
- Added second row of headers for ESP32 board connectivity.
- [Firmware v0.11_beta](https://github.com/srg74/WLED-wemos-shield/tree/master/resources/Firmware/WLED_wemos_shield/v0.11_beta_2011154) available for testing

### v1.3

- Removed resistor R1 connected to GPIO14. Instead of header placed IR receiver.
- Added on board momentary push button connected to GPIO0. Removed header.
- Added [WLED firmware v0.10.2 build_2010290](https://github.com/srg74/WLED-wemos-shield/tree/master/resources/Firmware/WLED_wemos_shield/v0.10.2_2010290)

### v1.2

- Added more space to accommodate different size ESP32 mini boards. Apparently some boards are slightly bigger than the proto board.
- Added Wiki link to [3D printed enclosure](https://www.thingiverse.com/thing:4313485) by @rboers

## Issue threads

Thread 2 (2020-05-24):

Do you sell finished WLED-wemos-shield?

dioem1985, 2020-05-24:
Hello, sorry I choose this way to write to you. Do you also sell assembled WLED-wemos shields? Would love to buy a few from you. Do you have an email address? Would also leave mine here if they sold me one or more WLED-wemos-shield. I come from Germany and have only started soldering since last year.
Sincerely yours
dioem1985

srg74, 2020-05-24:
Hi. This is open source project and you can ask questions. As of right now I don't assemble and sell shield. All my intend was to help WLED community with affordable DIY solution. Especially for the beginners. Nova days most of the projects using SMT components and for the beginners very difficult handle them and expensive.
You can order PCB and parts very cheap. Talk to your friends DIYers and assemble few PCBs for yourself and friends - have fun. People doing classes for the assembly and fun. Old people who never hold soldering iron in their hands. Participate https://wled.discourse.group/ and you find people from Germany who already doing shield or think about it.
If nothing above is good for you. You can buy similar board from Quinled.
Best regards.

dioem1985, 2020-05-24:
Thank you for your reply

dioem1985, 2020-05-25:
Hi,
I just ordered the pcb from pcbway, thanks for that. Can you please give me a precise list of the parts you need, with the exact description of the parts? Thank you very much for your effort.
Sincerely yours
dioem1985

srg74, 2020-05-25:
Did you navigate repository? https://github.com/srg74/WLED-wemos-shield/blob/master/resources/BOM.pdf

dioem1985, 2020-05-25:
Unfortunately I missed that.  Thank you very much.  Sorry if I annoy you so much.

srg74, 2020-05-25:
Np

srg74, 2020-06-14:
Solved

Joshfindit, 2022-03-07:
I found this issue by searching for PCBWay, and wonder if you could share the complete project through https://www.pcbway.com/project/shareproject/

Two benefits:
1. People would be able to order PCB and all parts at the same time
2. There could be an SMD version that people could order assembled for extra cost

netmindz, 2022-03-13:
+1 for shared project

Closed 2020-06-14.

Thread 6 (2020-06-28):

Wrong value for F2 & other PTC fuse?

WoodyLetsCode, 2020-06-28:
Hello,
the value of F2 (RUSBF075-APHFCT-ND) in your BOM is _30V 500mA_, but it is a **6V 750mA** fuse.
And aren't 6v a little bit too low? For example when somebody accidentally connects it to 12V :sweat_smile: it is possible that electricity arcs over the fuse.
Wouldn't this PTC fuse be better?
DigiKey: [507-2375-ND](https://www.digikey.de/product-detail/de/bel-fuse-inc/0ZRG0075FF1E/507-2375-ND/9468224)

srg74, 2020-06-28:
Thank you for your correction. Fixed in update.

WoodyLetsCode, 2020-06-28:
How do you make this BOM pdf file?

srg74, 2020-06-28:
I'm a Mac user so using a Numbers for spreadsheets. On DigiKey website I'm creating BOM file then exporting as CSV and then editing in Numbers to what you see. After just instead of printing save as PDF. Done!

WoodyLetsCode, 2020-06-28:
Can you also export it as .XLSX-File, so other users can edit it with excel?Am 28.06.2020 19:03 schrieb srg74 <notifications@github.com>:
I'm a Mac user so using a Numbers for spreadsheets. On DigiKey website I'm creating BOM file then exporting as CSV and then editing in Numbers to what you see. After just instead of printing save as PDF. Done!

—You are receiving this because you authored the thread.Reply to this email directly, view it on GitHub, or unsubscribe.

srg74, 2020-06-28:
I don't who else need to edit this file, but I did a copy in XLSX

WoodyLetsCode, 2020-06-28:
Thank you! :smile:

Closed 2020-06-28.

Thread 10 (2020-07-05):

Overvoltage protection

WoodyLetsCode, 2020-07-05:
Hey,
are you interested in adding an overvoltage protection?

srg74, 2020-07-05:
Over voltage protection is not simple circuit and no TH version. First it will make project more expensive and more complicated. Both issues is against idea to make as simple as possible and not expensive.

WoodyLetsCode, 2020-07-06:
What if you use this part as DC DC converter:
Digikey: [1589-1488-ND](https://www.digikey.com/products/en?keywords=1589-1488-ND)

This would have some advantages:

1. We don't need a power selector any more
2. It doesn't matter if you connect 5V or 12V power supply
3. You cannot destroy your WEMOS by setting power selector to wrong voltage

srg74, 2020-07-06:
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

Looks like you found a golden drop in replacement! But only one downside is price :( So actually we can add as more expensive alternative and eliminate header for selector and add a option to make a permanent wire jumper for universal voltage input. If you want you can add this option to Wiki and I will change BOM part as alternative. Only my worry is very low current 300mA. For ESP32 maybe near a limit, they very hunger sometime :)

WoodyLetsCode, 2020-07-11:
>
>
> Over voltage protection is not simple circuit and no TH version. First it will make project more expensive and more complicated. Both issues is against idea to make as simple as possible and not expensive.

Hey, over voltage is not very complicated. You can use a [Gas Discharge Tube Arrester](https://www.digikey.com/products/en/circuit-protection/gas-discharge-tube-arresters-gdt/142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) or a [Varistor](https://www.digikey.com/products/en/circuit-protection/tvs-varistors-movs/141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) or both. 😄 Both parts are not very expensive. They are not very complicated to solder. You can mount them through hole. And now we have options so you can make it optional to add an overvoltage protection.
There are many easy guides in the internet how to use a Gas Discharge Tube Arrester or Varistor.
I hope this is useful. 😃

srg74, 2020-07-11:
I would agree with you if proposed parts will be used to protect hi voltage AC input 120-240V :)

WoodyLetsCode, 2020-07-11:
Yes with this parts you can protect 120-240V.

WoodyLetsCode, 2020-07-11:
With  Gas Discharge Tube Arrester you can only protect from DC Overvoltage. But with a Varistor you can protect from both.

Closed 2020-09-02.

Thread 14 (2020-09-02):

esp32 - seems not to work with wled_base_2007020.bin

Jojopirat, 2020-09-02:
I flashed my ESP32 (form factor Wemos D1 Mini) with wled_base_2007020.bin from https://github.com/srg74/WLED-wemos-shield/tree/master/resources/Firmware/0.10_2007020/ESP32. Wifi and the web interface work, but neither the relay nor the OLED work. With an ESP8266 at least the relay works. I haven't been able to test LEDs yet.
What do I have to consider if I want to use an ESP32 instead of an ESP8266 and which OLED display is supported?

srg74, 2020-09-02:
I'm sorry for your inconvenience. Looks like file wled_base_2007020.bin is corrupted. Please use tested wled_base_2008310.bin
OLED display is no name 0.91" I2C similar to this https://github.com/srg74/Controller-for-WLED-firmware/blob/master/resources/controller.jpg.
ESP32 working just fine with amazing WLED firmware. Matter of fact it's a personal preference what people use.

Jojopirat, 2020-09-02:
Thank You for support.
With wled_base_2008310.bin on ESP32 relay and OLED-Display work fine now.

srg74, 2020-09-02:
I just posted fresh bin file with minor update. If you wish you can try this one. And you can connect button too :)
I assume you using my shield design.

Jojopirat, 2020-09-03:
I have now tried wled_base_2008310.bin with Led strips. It doesn't work with the ESP32. With the ESP8266 it works with clockless strips. Stripes with clock do not work on both CPUs.
Do you have an idea why?
I have than installed 0.10_2005030 on the ESP32. After this clockless led stripes work. But ESP32/8266 don't work together with my strip with the clock line.
Last xmas I used this four wire stripe without your board and with self compiled wled firmware on an 8266 wemos d1 mini. So i had to configure pinout and typ of stripe in the source code. For this reason i wonder about firmware on your repository doesn't make a difference.
May I have to compile wled on my own to support my configuration?

srg74, 2020-09-03:
Bin files located in repository support only 3 wire addressable strips. Those is only a favor for people who is using board. I don’t sell them. So my board as also WLED project is open source and all changes in configurations should be addressed by users due to endless variants of the setup.
You definitely can configure your bin file accordingly. In this case look at schematic and you will find pinout table for shield.
Best regards.

Jojopirat, 2020-09-03:
I got it wrong. The information about the hardware supported by the board also included the 4 wire stripes. I wrongly assumed or had hoped that this also applies to the firmware. Your project is very good and I am delighted that you are sharing it with us. I also didn't expect that you would provide firmware for every variant, but I did not want to reinvent the wheel if there is already a variant of the firmware that fits my configuration.
So thank you again for sharing and your support.

srg74, 2020-09-03:
Thanks for a good words! Indeed board support variety of configurations including 4 wires LED strips. Like I said user can choose what needed to be connected I just provided possibilities. Plus I don’t have that many different LEDs to test every possible configuration. I can only provide bin files what I can test. Also a lot of people already using board and I know most of them using WLED discord channel and Discourse so if anyone have questions they can ask there too.
Again thank you for choosing my design :)

Closed 2020-09-09.

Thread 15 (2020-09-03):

WROOM32 not wokring, wrong data pin

neilpryde1984, 2020-09-03:
Hi

Just tried out today my WLED Wemos shiel, but got only one, white LED lighting. Connecting to the build in AP was successful, but changing led type and/or other settings didn't help.

After some troubleshooting, I figured out, that for this board, the datapin in the firmware is wrong. when i connect the leds datapin to D4 of the board (https://bit.ly/3gWNehp), the whole thing is working as expected.

I do not think, that this is a hw issue, I've 4 identical boards, all with the same behaviour..

Regards
Chris

srg74, 2020-09-03:
What version of the board are you using? Then check out schematic first. Data pins for Wemos D1 mini and ESP32 mini version is not same GPIOs. https://github.com/srg74/WLED-wemos-shield/blob/master/resources/schematic.pdf In schematic you can find pinout for both main board which can be plugged to shield.
You have to use custom bin file for ESP32 board to use with shield https://github.com/srg74/WLED-wemos-shield/tree/master/resources/Firmware/0.10_2008310/ESP32

neilpryde1984, 2020-09-03:
The board has a label "MIN132 V1.0.0" on it. according to the pin description on the board an also its shematic (https://ae01.alicdn.com/kf/HTB1mlmbdGWs3KVjSZFxq6yWUXXa2.jpg),  the D4 from the shield is the IO16. This corresponds with your shematics and agrees for the ESP32 firmware..

I'm sorry about such a "noob-like" question.. but i would'n ask, if I had not multiple boards with the same issue..

srg74, 2020-09-03:
There is no noob question :) You asking and it's good. Please let me know what version of shield are you using, also where did you download firmware file e.g. bin file.

neilpryde1984, 2020-09-03:
I'm using shields build up according your guide for the Wemos wled shield (
https://github.com/srg74/WLED-wemos-shield)
The PCBs were ordered a few days ago..

The current installed firmware is
https://github.com/srg74/WLED-wemos-shield/blob/master/resources/Firmware/0.10_2008310/ESP32/wled_base_2008310.bin

Except of the data pin, all is working fine (relais, display,..)
Unfortunately, I do not have any oscilloscope for checking what signal the
data pin on the header an screwblock has..

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

srg74, 2020-09-03:
Could you please re-download bin file and let me know if it working.

neilpryde1984, 2020-09-04:
thanks for the new firwmware. but it seems to be a step backwards.. now, display and ap are also "failing"/not working

srg74, 2020-09-04:
Just checked again bin file with same kind of board as you have and everything is working file.
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 Please erase your board and re-check all connections.

neilpryde1984, 2020-09-05:
A reset a day, keeps the troubles away ;)

The erase helped!! Now, everything is worjing fine with the latest ESP32
bin.

Thanks for your help!

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

Closed 2020-09-09.

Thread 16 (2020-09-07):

What is the maximum load i can connect to this?

Bosken85, 2020-09-07:
Hello,

First off, nice work! Really appriciate the time you've taken to make this. I was wondering what the maximum load is i can connect to this board. I have long SK6218 led strip that consumes a max of 15A. But i noticed the Relay has a max of 10A. Do i need to replace some parts of the board with higher capacities?

Kind regards
Kevin

srg74, 2020-09-07:
You absolutely correct about relay ratings. I don’t think you will find relay with similar footprint and higher current rates to replace on the board. Instead what you can do it’s connect external relay with higher ratings and switch with it. Also if you count Amps for your strip 60mA per LED this case almost never happened. So you can run without any modifications just for safety limit in WLED current max to 10000mA

WebOscar, 2020-09-30:
I found a 20A Relay, which should fit to your needs: https://www.aliexpress.com/item/32842347863.html?spm=a2g0o.detail.1000023.15.21953b72Bjcqy7
But I would also order the Boards with a thicker layer of copper. At least I did with 2 oz Cu to handle higher ratings and get less loss.

Greetings,
Oskar

srg74, 2020-09-30:
Very good find! I don’t know if this relay will hold actually 20A but there’s a possibility :) please be very cautious when using big load.

WoodyLetsCode, 2020-12-12:
Hey,
i added a FAQ for this:
https://github.com/srg74/WLED-wemos-shield/wiki/FAQ#what-is-the-maximum-load-i-can-connect-to-this

shortbloke, 2021-01-09:
@srg74 Hi I've just taken delivery of some of the 20A relays suggested and their pin spacing is 10mm rather than 12.2 used with the original 10A relay. So not a drop-in replacement with your current PCB layout. Probably can be made to fit with some carefully drilling of new holes. But a bit of a bodge.

srg74, 2021-01-09:
> @srg74 Hi I've just taken delivery of some of the 20A relays suggested and their pin spacing is 10mm rather than 12.2 used with the original 10A relay. So not a drop-in replacement with your current PCB layout. Probably can be made to fit with some carefully drilling of new holes. But a bit of a bodge.

Sorry for wrong information about relay. Unfortunately I don't tested myself. On of project user recommend as drop in replacement. Can you post exact dimensions or data sheet and I will see what can be done for future board.

shortbloke, 2021-01-10:
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

This comes from the AliExpress link. Though section 4 mentions both 20A and 10A as the rating, I'm not sure I'd trust this at 20A, it seems so small!

srg74, 2021-01-11:
I have read data sheet and I can say it's not a 20A relay but only 15A.

MFornander, 2021-01-26:
> I found a 20A Relay, which should fit to your needs: https://www.aliexpress.com/item/32842347863.html?spm=a2g0o.detail.1000023.15.21953b72Bjcqy7

Just another note that I went ahead and ordered the relays here and the spacing is indeed too small, just in case it was just a bad shipment.  So link above should not be used.

Closed 2021-04-01.

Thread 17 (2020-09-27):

Replacement for a 1000uf 25v capacitor

slakin, 2020-09-27:
Hi, thanks for your project. I already done several shields and they works flawlessly.
My question is can I use 1000uf 16v capacitor instead of 25v? 25v version is too high for my enclosure.

srg74, 2020-09-27:
Basically if you using 5V LED strips you can use lower voltage capacitor. General rule for capacitors is (powers supply voltage)x2 = capacitor voltage.

Closed 2020-09-27.

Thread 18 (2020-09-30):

Question about Fuse F1

WebOscar, 2020-09-30:
At first, thank you so much for your great work! I just ordered 150 boards for a lot of own Smart-Home-projects and for some Friends, who are such nerds! ;) And 10 sound reactive boards for testing. I hope PCBWay will pay you the promised 10% as I have not found your "Buy me a Beer"-Button! ;)

I have a question about fuse F1. Unfortunately the BOM does not list which fuse should be inserted there. Don't I have to calculate down the ampere of the 32V fuse for a voltage of 5V?

If I calculate with a maximum of 10A at 5V, because the relay should not switch more, then I think that I have to convert the corresponding values of the fuses, which are indicated with a nominal voltage of 32V, or am I wrong?

With 10A, 5V I get 50W which is about 1,6A at 32V. The next suitable fuse would be 0297002.WXNV (Digikey), right?

Greetings from Germany,
Oskar

srg74, 2020-09-30:
Actually fuse rating have to be calculated like this Calculated maximum Amps X 1.25 = Fuse Amps. 32V DC is maximum that fuse can hold. Those fuses is automotive so it nom 12VDC.
You are very kind to your friends :) Thank you for your generous words

WebOscar, 2020-09-30:
Oh dear, now I'm confused!

Okay, let's say 10A, 5V is the max I want to protect. 10A x 1,25 = 12,5A * 5V = 62,5W

What are the 12,5A now for the automotive fuses?

Lets assume that the specifications on the fuse refer to a nominal voltage of 12V. Will I have to use 62,5W / 12V = 5,2A for using this fuse with 5V (round up or down to the next suitable value of a fuse) or will I use a 15A fuse (I think, there's no other between 10A and 15A) as calculated for 5V, regardless of the nominal voltage of the fuse?

Do you know, what I mean?

WebOscar, 2020-09-30:
Okay! I found the answer! The fuse is limiting the current, regardless of the voltage. The 32V in the example above only gives the safe "isolated up to 32V" value.
Learned a lot about fuses, today! Thanks for your fast answer!

srg74, 2020-09-30:
Let me clarify. With fuse you protecting your circuit from over current. So in general it’s related to your wire gauge (AWG). Now after you calculate proper wire gauge for your project it’s tell you what Current it will can carry. Now you can multiply that number to 1.25 and result will tell you what nominal Amps fuse have to be.

WebOscar, 2020-09-30:
Oh yes, that's clear; thanks! I only got lost in calculation as the fuse came up, which wasn't necessary at all, as I know now.
One last Question (I hope). Is the PS1 - as I understand is a step down converter - needed when it is clear, there will be only 5V used?

srg74, 2020-09-30:
Yes step down buck converter is optional. You can build only a with components is necessary for your project functionality. Starting from https://github.com/srg74/WLED-wemos-shield/wiki/Bare-minimum and build up to whatever fit your project.

WebOscar, 2020-09-30:
Oskar, RTFM! Dammit! Thanks for the link. I missed that! Now I have a lot of capacitators and resistors left!
RTFM, RTFM, RTFM, RTFM...

Closed 2020-09-30.

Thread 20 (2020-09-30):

Audio jack replacement

rboers72, 2020-09-30:
I want to build the audio version of the WLED-wemos-shield and I have some PJ-210B audio connectors lying around. Is there any reason why I shouldn't use these instead of the SJ1-2503A?
I compared them, and they look the same.
The PJ-210B is a perfect fit in the PCB.

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

huggy-d1, 2020-09-30:
At a glance, the physical dimensions of the pins are slightly different, but with hole tolerances, I can see why you say it's a perfect fit.  The soldering of the device may be a tiny bit trickier to get proper flow through the holes to achieve expected mechanical support.  That said, if this is a connect it and forget it install, that's probably not a problem.

If you expect unplugging the connector a lot, I recommend using a sacrificial cable/connector.  Plug in the very short sacrificial cable into the PJ-210B and leave it connected all the time, and simply use the other end of the cable as the "field" side of the connector.  This also applies to many connections you expect to insert / remove often.  Using this approach protects the life of PCBs and original connectors, and instead wearing out an easily replaceable cable.

rboers72, 2020-09-30:
@huggy-d1 Thank you  for your reponse. I'm going to use this one, because I'm not going to connect/disconnect it a lot.

Closed 2020-09-30.

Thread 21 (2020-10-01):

Sound reactive board - bare minimum

WebOscar, 2020-10-01:
Hello again!

I couldn't find any extra bare-minimum documentation for the sound reactive board. (Or does it exist and I am just too damn dumb to see it?) So I compared the two BOMs to identify the extra parts the SR-board needs.

This is my result:

R8, R9, R10, R11, R12, C3, C7, F2 (different than the standard version), Audio Socket and SW1.

Am I right or did I miss something?

Greetings from Cologne, Germany
Oskar

srg74, 2020-10-01:
There is no guide for SR board,  since difference is only circuit for microphone and linear input. You found differences correct, just F2 is part of base circuit - it’s a fuse

WebOscar, 2020-10-01:
Thanks! I know F2 is a fuse, but according to the BOMs it is a different one as in the standard board. Standard board BOM lists a 16V 900mA while sound reactive BOM lists a 30V 500mA. That's why I marked it in my findings as different from standard, even I don't think it will make a difference.

Closed 2020-10-01.

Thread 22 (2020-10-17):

Flickering LEDs

ngrosc, 2020-10-17:
Hi

I tried my Wemos shields today with my "lighted bookshelf" and ran into some issues.

As soon as the LEDs are lit up, they start with some strange flickering. Also when i change the color, the whole strip flickers and switches then (most times) to the right color.

I know, that this can be related to power issues, but I'm sure, that my power supply is well dimensioned (10amps, 126 LED consuming max 7.5amps).

As soon as I touch the data wire leaving the sheild, everything works well. Also when I'm replacing the shield with another controller the flickering dissapears.

Do I need to somehow terminate the data wire at the last strip?
Or might it help, to use a level shifter as amplifier between the strips?

I know, that I'm not using the relay, but this should not be a problem, because I'm still connected to the same VCC and GND path or not?

Noob-style-wiring-diagram :D

```
                                                            +--------------------------------------+
+-------------------------------+                           |                                      |
|                         GND   +-------------+-------------+ GND                                  |
|                               |             |             |                                      |
|                         VCC   +------------------+--------+ VCC                                  |
|    WLED Shield                |             |    |        |          LED Strip 1 (18LED)         |
|                               |    DATA     |    |        |                                      |
|                         DOUT  +---------------------------+ DIN                            DOUT  +---+
|                               |             |    |        |                                      |   |
+-------------------------------+             |    |        +--------------------------------------+   |
                                              |    |                                                   |
               +------------------+  GND      |    |              +------------------------------------+
               |                  +-----------+    |              |
               |                  |           |    |              |    +----------------------------------------+
               |   PSU, 5V 10A    |  VCC      +------------------------+ GND                                    |
               |                  +----------------+              |    |                                        |
               |                  |           |    |              |    |                                        |
               +------------------+           |    +-------------------+ VCC      LED Strip 2 (18LED)           |
                                              |    |              |    |                                        |
                                              |    |              +----+ DIN                              DOUT  +--+
                                              |    |                   |                                        |  |
                                              |    |                   +----------------------------------------+  |
                                              |    |                                                               |
                                              |    |              +------------------------------------------------+
                                              |    |              |
                                              |    |              |
                                              |    |              |
                                              |    |              +--+    Strip3 -- Strip 4 -- Strip 5 -- Strip 6  +---+
                                              |    |                                                                   |
                                              |    |           +-------------------------------------------------------+
                                              |    |           |
                                              |    |           |      +-----------------------------------------+
                                              +-----------------------+ GND                                     |
                                              |    |           |      |                                         |
                                              |    |           |      |                                         |
                                              |    +------------------+ VCC     LED Strip 7 (18 Led)            |
                                              |    |           |      |                                         |
                                              +    |           +------+ DIN                                     |
                                                   |                  |                                         |
                                                   |                  +-----------------------------------------+
                                                   |
                                                   +

```

srg74, 2020-10-17:
Looks like you have a bad connection. Please move your discussion to Discord WLED https://discord.gg/KuqP7NE my nick there is serg74. And it would be good if you will post pictures of shield from both sides.

Closed 2020-10-26.

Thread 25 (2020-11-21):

v1.3 Not working. What I have done wrong?

waterfox207, 2020-11-21:
Hello,
and thanks for the nice project.
I have built the board in Version 1.3.
Sadly, it is not working, and I have no voltage output on the output pins.

So far, I have checked PIN D6 which should be the relay pin. If the wemos is not connected to board, I get a high and low signal (0 vs. 3.3 V). If I put the wemos on the board, I get 0 V and 0.4 V.
If I disconnect the board from the power supply and check for continuity D6 is connected to ground. I think this is not correct?

I have also added the switch to the board. All pins of the switch also have continuity with ground.
Furthermore, I do not know if JP3 needs to be connected or not?

What is the purpose of D3<BT>?

I hope someone can help me
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

WoodyLetsCode, 2020-11-21:
Hello,
did you check voltage between 5V Pin and GND Pin?
D3 is for a push button.

waterfox207, 2020-11-21:
Thank you for your fast response!
I about 5V between 5V Pin and GND Pin.

I thought SW1 is for the push button? Thats the place where my button fits.

WoodyLetsCode, 2020-11-21:
Did you turn on the LEDs in WLED?

waterfox207, 2020-11-21:
Yes, the blue led on the wemos also indicates the status of the led output. If the small blue led is on I think the lights are also on?

________________________________
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

WoodyLetsCode, 2020-11-21:
No, the blue LED on the wemos is always on. You have to turn on the LEDs in the Web-GUI. Do you hear a "click" from the relay noise when you connect it to power?

waterfox207, 2020-11-21:
When I connect the board to power. There is no noise from the relay.
Hmm I also think there is some "magic" going on. When I now place the wemos on the board the blue light only flashes once.
I have also no access the the Access point of the wemos.
If i connect the wemos via usb, everything works fine.
Maybe I have done a pull down resistor wrong?

WoodyLetsCode, 2020-11-21:
Can you send a picture how you put in the wemos?

waterfox207, 2020-11-21:
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

srg74, 2020-11-21:
1. Upload code to you Wemos board and make sure everything is woking fine without shield. Means connection to your network and navigation by GUI.
2. Check out your board without Wemos connected. Make sure board have no shorts. It have to be 5V on headers marked 5V (I assume your board is 5V only).
3. Plug your Wemos. If everything done correct (you check your boards and firmware is correct) than upon power ON you can hear a click from relay, means it's working correct. Now shutdown power and connect your LED strip to board. Power ON and yours LEDs have to be orange.
Basically board don't have a lot of parts and it's very simple to repeat (proven by many users before)

waterfox207, 2020-11-21:
I found my mistake!
For R3 I have used a 10 Ohm resistor and not a 10k Ohm one. 🙈
I will tell you my result when I have changed it.

I also have now removed the button. Because of the continuity check. So far, the wemos is now also working on the board and D3 isn't shorted to ground anymore. I think maybe there is a misstake in the gerber or my button does not work like the ones from digikey. My button is connected to ground on the housing. So, both bigger pins are connected. I think that this is the reason for the short circuit on the d3 pin.
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

Thank you for the hint with the fuse. I was not able to order the fuse holder from the BOM. When I receive the right fuse holder, I will replace it.

srg74, 2020-11-21:
Definitely SW1 have a gerber error. I will fix that immediately. Thank you.

waterfox207, 2020-11-21:
Perfect.
Thank you for this nice Projekt. 🤙

Closed 2020-11-21.

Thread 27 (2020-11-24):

Bare minimum - Not working

Dragi2k, 2020-11-24:
Hello,

i have Build the Board and its not Working.
Is it Possible that "R8" is needet ?

WoodyLetsCode, 2020-11-24:
Hello,
R8 is not needed for Bare minimum. Can you give more informations? What exactly is not working? Can you send a picture of your assembled board? What are the results of the [check](https://github.com/srg74/WLED-wemos-shield/wiki/Check) steps?

Dragi2k, 2020-11-24:
Nur if i shorten r8 it works fine 🤔
![Uploading 1606245926359932586524304444191.jpg…]()

Dragi2k, 2020-11-24:
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
And the Fuse holes are also wrong, but i dont know, ob this false by pcb-way is

srg74, 2020-11-24:
Some how resistor R8 150 Ohm. You do need this resistor for minimum configuration. Look at BOM v1.3 because your board is v1.3. You can find archive here https://github.com/srg74/WLED-wemos-shield/releases/tag/v1.3

Dragi2k, 2020-11-24:
I know, fuse is in the way 😉
But what is with the holes of the Fuse holder?
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

srg74, 2020-11-24:
Where did you order your PCB?

srg74, 2020-11-24:
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

Dragi2k, 2020-11-25:
Over your link, on pcb-way

srg74, 2020-11-25:
In this case you have contact PCBway and explain that your board came not routed. They have repeat your order it's their responsibility.

Closed 2020-11-25.

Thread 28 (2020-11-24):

Resistors R1 / R8

Ryanb369, 2020-11-24:
i may be blind, but the value for R8 is not listed on BOM. I can't seem to find R1 on the board either. Thanks for the info in advance.

WoodyLetsCode, 2020-11-24:
Hello,
R1 is next to the 8-Pin header. Where do you see R8? I think R8 doesn't exist, or am i wrong?

Ryanb369, 2020-11-24:
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 R8 is right in the middle, could that be R1?

WoodyLetsCode, 2020-11-24:
Oh sorry. I don't have the new v1.5 board. I just have the older ones. But I'm sure @srg74 can help here. 😃

srg74, 2020-11-24:
Resistor you asking is not R8 but R2 150 Ohm

Ryanb369, 2020-11-24:
Is there a value for R8? Or is this not needed

srg74, 2020-11-24:
Please read right above :)

srg74, 2020-12-06:
Errors fixed

Closed 2020-12-06.

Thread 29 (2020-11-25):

D1 not booting when connected to 12v

Ryanb369, 2020-11-25:
The D1 blinks once and goes dark. Led indicator on wemos-shield  is lit up. D1 is fine when connected via usb. Unsure of why, 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

WoodyLetsCode, 2020-11-25:
Hello,
what are the results of the [check](https://github.com/srg74/WLED-wemos-shield/wiki/Check) steps?

Ryanb369, 2020-11-25:
All the voltages are as the should, at jumpers and board inputs.

srg74, 2020-11-25:
Please remove push button from the board. Early batch of PCBs have error. If you comfortable to cut traces I can explain what to cut.

Ryanb369, 2020-11-25:
I'll desolder the button, i believe i have pcb 1.5

srg74, 2020-11-25:
So is it working now?

srg74, 2020-11-25:
Also for quick response you can reach me https://discord.gg/KuqP7NE  as @Serg74

kallejoken, 2024-08-06:
> So is it working now?

I have exactly the same problem with version 3.0, I didn't solder the push button. Do you have any help?

srg74, 2024-08-06:
Version 3.0 don’t have errors and works for 2 years without problems

kallejoken, 2024-08-06:
> Version 3.0 don’t have errors and works for 2 years without problems

yes exactly, but only if I apply the fix as described here https://github.com/srg74/WLED-wemos-shield/issues/107

srg74, 2024-08-07:
Problem here is most likely due to different design of mini board used. But in this post you can find solution for the issue.

Closed 2020-12-19.

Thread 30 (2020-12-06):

R2 required for v1.5 bare minimum

SvenFestersen, 2020-12-06:
First of all thanks for this awesome shield! I just assembled my first v1.5 bare minimum board + temperature sensor. However, I was not able to turn the LEDs on on the first try. A look at the schematic revealed that R2 is actually required as it connects the level shifter output to the screw terminal. I soldered a 120Ohm resistor in that place (no 150 Ohms at hand) and it now works like a charm.

So I suggest updating the "Bare minimum" page to include R2.

srg74, 2020-12-06:
New WiKi in the work as of right now. So your remark will be reflected there.

WoodyLetsCode, 2020-12-12:
Hey,
I updaded wiki. Now R2 is mentioned in [bare minimum](https://github.com/srg74/WLED-wemos-shield/wiki/Bare-minimum).
I also added a FAQ for this:
https://github.com/srg74/WLED-wemos-shield/wiki/FAQ#do-i-need-r2

Closed 2020-12-19.

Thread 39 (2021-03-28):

PCB v2.0 setup issue

ChristophA, 2021-03-28:
Hi,
thank you very much for this cool project! I recently ordered come PSBs v2.0 and the required parts. While assembling a minimum setup I struggled to find the correct place for the fuse F2. There's no lable on the PCB for F2. But after a while i figured out to place in on the right hand side of D2. Maybe it's worth to add a lable for F2 on the PCB!?

A Wemos D1 Mini (also tested with D1 Mini pro) is now starting and accessible viw the webinterface. I confiugre the relay to use pin / GPIO 12, works as expected. LED out (DI) is configured to use pin / GPIO 2. But I cannot light any LED. Not sure if my setup is correct. I've also added R1 and R2, but still no light. Firmware is the latest v0.12.0-b3

Is there anything missing?

Many thanks for any hint!

PS: Still waiting for the fuse holder, therefore I'vs added a short cable just for testing.

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

srg74, 2021-03-28:
First  of all your IC is different from which project is using. 74HCT126 is a buffer not a shifter. I don't think it will work.

ChristophA, 2021-03-28:
I've double checked everything 10 times. Everyting but this chip...
Thank you very much, I'll replace it wit a 74AHCT125. For some reasons 3 of these 126ers are in the box with the 125ers. Don't no were thes come from.

I'll report back once replaced.

ChristophA, 2021-03-28:
All good now! Thanks again for pointing me in the right direction!

Closed 2021-03-28.

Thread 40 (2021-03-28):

WS2815 with two Data-Lines, any possibility to use both?

tugsi, 2021-03-28:
Hi,
first of  all thanks for your Shield.
Ive used one with a WS2812-Stripe, perfect.
But now I build one for outdoor and want use it with WS2815 12VDC.
my first test works fine, but there is still one question, nowhere found a solution in your Wiki or anywhere else.
The WS2815 works with two DIs, one is for StandBy, if anything happens with the first one.
Was there a way to connect and use the DI2?

Best regards
Thomas

srg74, 2021-03-28:
You have 2 data lines one is marked DI and second is BI. According to data sheet of WS2815 DI is digital input and BI is backup, at first pixel it have to be tight to Ground (GND)

tugsi, 2021-03-28:
Thanks for the answer.
I've forgotten a not entirely unimportant thing, I still have the v1.0 design.
There is no BI, only CLK.

srg74, 2021-03-28:
No better which version you using they all backward compatible with software and strips. BI wire from strip have to be connected to GND not CLK. CLK is a clock pin for APA102 strips. And with newest beta firmware you can use 2 strips per controller even v1.0 :) Just make sure all strips together do not exceed 10A current.

tugsi, 2021-03-28:
Ah, ok, now I understand ;)
I can use 2 stripes?
At the moment I have hung the two stripes one after the other for testing (600 LEDS).
Works well, even without an additional feed of the second stripe.
In the final setting, I probably feed the second stripe in separately so that everything doesn't run over the first and it gets too warm.

Closed 2021-04-01.

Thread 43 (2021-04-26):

Which document is the correct?

florianmulatz, 2021-04-26:
Hi,

To be honest, I don't know my way around anymore.
There are different BOMs and different PCBs in the repository.
I have ordered the v2 of the PCB and the bare-mininum parts of the BOM v1.3, but now seems not to fit perfectly.

Please info what is correct now - which BOM belongs to which PCB and maybe then I could help updating the soldering instructions. I'm not sure if the thing should work now.

And the Bare-Minimum list tells R8 - where should this one go? I don't find it on PCB. thx

srg74, 2021-04-26:
Don’t worry, everything is fixable. Schematic and BOM is not changed a lot since version 0.93. Difference between versions is more functionality and convenience. Recent BOM pdf is good for ordering parts. They will fit on all versions. Only one “big” difference from previous versions is headers 10x2 female. But it obvious if you just look at PCB. If you have a further question it’s quicker when you ask at WLED Discord. I can answer you there in real time.

Closed 2021-05-05.

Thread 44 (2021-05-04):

Support for multiple LED outputs

CWempe, 2021-05-04:
I just read the changelog of [WLED version 0.12.0](https://github.com/Aircoookie/WLED/releases/tag/v0.12.0).
It supports multiple LED outputs.

I guess you could still use just one relay to power on/off all led strips at once.

The level shifter (SN74AHCT125N) is already able to support up to four outputs, too.

Only the additional terminal blocks would need more space, I think.
But maybe we could keep using one `GND` and one `+` for all strips and only add the extra `DI` (and `CLK`?).

I really would like to use a shield with support for at least two LED outputs. 😎

srg74, 2021-05-04:
You can use both DI and CLK as data pins. If you using board v2 also you can set soldering jumpers for 2 more outputs. All available outs shifted. Only downside In this case you can’t use digital microphone.

CWempe, 2021-05-04:
> All available outs shifted.

Great! I did not expect that.

In that case I do not need a new design. 👍

Closed 2021-05-04.

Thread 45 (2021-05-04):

Improve README

CWempe, 2021-05-04:
It has been a long time since I setup this shiled with WLED . :)
So took me a few minutes to get it working again this time.

My issues were:

* I was not sure what pins are used by this shield.
*   I guessed correct it uses the [default pins](https://github.com/Aircoookie/WLED/wiki#default-gpio-usage)
* I forgot to set the relay pin. So the LEDs stayed off at first.

Maybe this information should be added to the README.

srg74, 2021-05-04:
Actually all pins are described in schematic. Pinout available for esp8266 and esp32 boards.

CWempe, 2021-05-04:
I knew I could look for the pins in the schematic or the pcb design.

I just think it would make it easier for the average user if they were mentioned in the README.
Or maybe a short sentence with a link to the schematic.

just my 2 cents 😉

srg74, 2021-05-04:
You absolutely correct. For average user it have to be pointed. Project in constant development and better more clearer navigation in plans.

Closed 2021-05-05.

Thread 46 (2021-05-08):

FAQ about maximum load is unclear

CWempe, 2021-05-08:
> The maximum load you can connect is 10A. With greater loads traces leading to and from relay contacts have to be soldered with access of solder to make them ticker due to higher current.

So I can use more than 10 A if I add solder to the traces?!
I just noticed the recommended relay `SRD-05VDCSL-C` has printed `10 A` in the top.

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

1. So I guess even with bigger "with access of solder" you cannot/should not use more than 10 A.
2. If the traces (with more solder) can handle more load: Is there a compatible relay available that supports more load (e.g. 15 or 20 A)? Or should this be avoided for this shield anyway?

Maybe the FAQ can be more clear about this.

srg74, 2021-05-08:
I would say it's safe to run 10A with default relay. Actually if you want to run more then 10A you can connect of board relay with greater ratings and proper wiring. One of the user used 15A relay substitute, but I think it's absolute limit because traces on board can't withstand more current.
You can try to find replacement relay by comparing relay dimensions and pin distances. Everything is available in data sheets.

CWempe, 2021-05-08:
> You can try to find replacement relay by comparing relay dimensions and pin distances. Everything is available in data sheets.

Yes. But maybe you already knew one. 😉
But I think 10A will be sufficient for my projects.

I also noticed the terminal blocks are rated for a maximum load of 13,5 A.

So I would suggest to explicitly not recommend more than 10 A in the FAQ.

Like:
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

srg74, 2021-05-08:
Wiki updated.

zurkes, 2021-05-14:
if you want to high loud look it https://wiki.faked.org/DIY_Ambilight

Closed 2021-05-09.

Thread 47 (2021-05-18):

12v Support

florianmulatz, 2021-05-18:
Hi,

i've ordered these ones from aliexpress (https://www.aliexpress.com/snapshot/0.html?productId=32848919879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) in 10µF (the only "technical" difference from my point of perspective is that they are suitable for up to 50V) for 12V Compatibility - they does not fit perfectly but it's acceptable. I guess these should also work as C4, C5 right.

I'm asking because after I have soldered them and put the Jumper to 12V and added a 12V PSU - the esp does not light up anymore.

Maybe it's a misunderstanding and the 12V Support is only supported for OUTPUT.

Cheers

shortbloke, 2021-05-18:
Did you also install PS1 a VXO7805-500 DC to DC converter to provide 5V to your MCU when using a 12V PSU and 12V LEDs. The AliExpress link doesn't work for me, so I can't see what caps you used for C4 and C5. Also ensure you mount the VXO7805-500 the correct way round.

florianmulatz, 2021-05-18:
ah - that looks to be the culprit! I've completely overseen that component. this should be the correct link for the caps --> https://de.aliexpress.com/item/32848919879.html?spm=a2g0s.12269583.0.0.7ad86a4aEK2JGo. Hm would be challenging to add the dc-dc converter as well because of the too big caps now.

shortbloke, 2021-05-18:
The DC-DC converter does come with 3 right angled header pins, so it can be elevated off the board a little which might provide enough clearance for your larger capacitor pair.

florianmulatz, 2021-05-18:
Sounds legit. Do you think the caps will fit? - thx for your  help indeed!

srg74, 2021-05-18:
> Sounds legit. Do you think the caps will fit? - thx for your help indeed!

Please, for troubleshooting come to WLED discord and we can resolve it quickly.

florianmulatz, 2021-05-20:
connected :) - thx in the meantime

Closed 2021-05-20.

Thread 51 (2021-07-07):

What's about the possibility to use more than one stripe with a single esp32

Aussiedler, 2021-07-07:
Hi, I have a question about your board. If I understood correctly, the power supply for the board itself can be selected up to 24V. LED strips there are but only 5-12V right? The DC-DC converter converts only the power for the esp32 right? The stripe will get the full 5-24V which is specific from the selected power supply, right?

I was looking for a variant with an ESP32, because with this it should be possible to connect 10 strips simultaneously and 4 strips productively. Well your board actually fulfills all wishes. But with you I see only the connection option for one strip, or am I mistaken here?

Thanks for the help!

srg74, 2021-07-07:
Hi. Yes you understood correct. Board able to handle 5V or 12/24V power supply and strip must be same voltage. Means 5V PS and 5V LED strip or 12V power supply and 12V LEDs. Regarding quantity of the connected strips 4 strips maximum if you configure regarding your setup. In this case sound reactive feature with microphone is not possible. But possible with linear audio input. Actually quantity of the strips is not beneficial only make sense if your setup is required connections in one point.

Aussiedler, 2021-07-07:
Thanks for the quick feedback! In my case I have a large room with 2 supply points where 5x25mm² cable. A total of 30m LED strips must be connected. I had considered using 2 WLED controllers which control 2 lines each. So I would have per line 7-8m or 420-480 LED pixels per line. The ESP32 should be able to handle that.

How is another stripe connected to your board?

srg74, 2021-07-07:
Here is pinout for entire board https://github.com/srg74/WLED-wemos-shield/blob/master/resources/Images/wiki/Wemos_shield_pinout.pdf

Closed 2021-07-09.

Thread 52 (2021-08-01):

Thoughts about Assembly-Wiki

CWempe, 2021-08-01:
I ordered a few v2.0. board a while ago and am going to solder them now.
Lucky me, v2.1 has been released since then. 😅

Anyway.
I will try to follow the [Assembly-Wiki](https://github.com/srg74/WLED-wemos-shield/wiki/Assembly).
But here are already a few thought after reading the guide.

1. I think it would be nice if the parts that are only for v2.1 were marked accordingly.
  But maybe there are not many people who have the older version 2.0.
2. Chapter 1: `IO15 - Let you choose if your output 15 is shifted or not (soldered left not shifted);`
   a. I guess `output 15` is a pin on ESP32? So I can ignore this for my ESP8266?
   b. You mean: "Let's you choose/define if your output 15 should be shifted or not". Right?
3. Chapter 1: `IO15-1 - Must be soldered if output 15 is shifted;`
  "Must be soldered if IO15 is soldered, too." But I am not quiet should sure if this is what you mean.
4. Capter 1: `J-R2` and `J-R1`
  Would be nice if you would linke to the [option](https://github.com/srg74/WLED-wemos-shield/wiki/Options) this is related to.
  As a "dumb user" I am not sure if I need there resistors. At least not without further research of the wiki.
5. Chapter 2: `Check orientation with markings on PCB.`
  I would indent this line as a sub item from the Diodes line above.
6. Chapter 7: The image does not work.
  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
7. Chapter 2: I think you forget to mention R2. It is soldered in the image.

Thank you anyway for the Assembly-Guide! 👍

srg74, 2021-08-01:
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

All parts remain unchanged. No major changes where performed.

> 2. Chapter 1: `IO15 - Let you choose if your output 15 is shifted or not (soldered left not shifted);`
>    a. I guess `output 15` is a pin on ESP32? So I can ignore this for my ESP8266?
>    b. You mean: "Let's you choose/define if your output 15 should be shifted or not". Right?

Additional shifted outputs only for ESP32

> 3. Chapter 1: `IO15-1 - Must be soldered if output 15 is shifted;`
>    "Must be soldered if IO15 is soldered, too." But I am not quiet should sure if this is what you mean.

Yes, if you shifting output jumper with PIN-1 must be soldered too.

> 4. Capter 1: `J-R2` and `J-R1`
>    Would be nice if you would linke to the [option](https://github.com/srg74/WLED-wemos-shield/wiki/Options) this is related to.

There is explanation for those. R2 is only enabled if you have a old LED strips. R1 only enabled if your board is not stable without pull-up resistor.

>    As a "dumb user" I am not sure if I need there resistors. At least not without further research of the wiki.

There is not such a thing as dumb user. Everything take a learning curve. Any electronic project is not a toy.

> 5. Chapter 2: `Check orientation with markings on PCB.`
>    I would indent this line as a sub item from the Diodes line above.

Fixed, for more clear understanding.

> 6. Chapter 7: The image does not work.
>    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

Fixed

> 7. Chapter 2: I think you forget to mention R2. It is soldered in the image.

Read ["Options"](https://github.com/srg74/WLED-wemos-shield/wiki/Options) first

CWempe, 2021-08-02:
> All parts remain unchanged. No major changes where performed.

I literally stumbled on the first line.
I cannot find any `IO1-IO3` an my v2.0 pcb.
But this might be the only change. 😄

> There is explanation for those. R2 is only enabled if you have a old LED strips. R1 only enabled if your board is not stable without pull-up resistor.

I just think it would be easier for the user if you link to these explanations.

> Fixed

There are no red traces in the image. 😉
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

CWempe, 2021-08-02:
And I just found out the `TTGO T7 V1.3 MINI 32 ESP32` does not really fit. 😕

I gues I will get it to work.

But maybe this should be mentioned in the assembly guide.
The user could insert the ESP32 before soldering the relay.
It would fit if the relay would be slightly pushed to terminal connectors or angled a little.

srg74, 2021-08-02:
Actually it's a manufacturer problem. They have a production with not consistent board size. When I add this board to Wiki USB port was 0.5mm from relay, with relay in correct position.

CWempe, 2021-08-02:
> Actually it's a manufacturer problem. They have a production with not consistent board size. When I add this board to Wiki USB port was 0.5mm from relay, with relay in correct position.

I guess that is the downside of a low priced DIY project. 😄

srg74, 2021-08-02:
I would not say downside. It's a manufacturer who really don't care about customers. My boards working in 1000's quantities and most of the time with no problem. Shield was tested very vigorously by many users and recent version have no complains. Also if you don't like DIY there is fully assembled and individually tested version available.

CWempe, 2021-08-02:
I did not mean your project is bad.
I meant chinese manufacturers are sloppy.

If we would use expensive parts for our projects this would not be an issue.

You are doing a great job with this project!. 👍

srg74, 2021-08-03:
No offense taken. I'm just trying to explain how project was evolving. Parts gotta be a good quality but not expensive. That was a goal.

Closed 2021-08-25.

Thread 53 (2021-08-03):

Sound reactive build 2108010 bricks ESP32

lanman1, 2021-08-03:
OTA build 2108010 bricked ESP32 using both with/without display.  Had to re-flash with USB

srg74, 2021-08-03:
I will check firmware and if this fixable I will update files

lanman1, 2021-08-03:
Thanks!  No problem, just letting you know.

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

srg74, 2021-08-03:
Fixed :)

lanman1, 2021-08-03:
Must be me, When I try to do an OTA update of my TTGO ESP32, it bricks with
the predone bin.  I then have to reflash with USB.

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

srg74, 2021-08-03:
Again? With new bin files?

lanman1, 2021-08-03:
yes.  I have run 13. on this before and it is ok.  If I'm on 12.0, I upload the bin via OTA and the ESP just lock up at reboot.  No relay click, just locks.

lanman1, 2021-08-03:
The non-SoundReactive v0.13.0-b2/esp32_no_mods.bin works ok.  But both SoundReactive bin do not.

srg74, 2021-08-03:
TTGO ESP32 T7 v1.3?

lanman1, 2021-08-03:
Yes.  As information, it appears to be related to presets.  I did a factory reset and was able to load the soundreactive bin ok but there is no option to backup/restore presets.  I flashed back to the non SoundReactive and preset backup/restore is there.

srg74, 2021-08-03:
So you did fix your board and bin files is ok? Presets backup your_wled_IP/edit

lanman1, 2021-08-03:
There seems to be an issue with soundreactive bin files.  There is on backup/restore option in the soundreactive bins and if presets exist before flashing soundreactive, the board locks up.

srg74, 2021-08-03:
Yep, I can confirm. In this case have to report to sound reactive fork.

lanman1, 2021-08-03:
Thank you.  Let me know if I can help test, thank you for posting the .bin(s)

srg74, 2021-08-03:
I already posted question to devs. If glitch will be fixed I'll post result here.

srg74, 2021-08-04:
After some clarification I found that bin files is OK. To back up presets. you go to IP_wled/edit -> right click on file presets.json and save file.

lanman1, 2021-08-04:
Ok.  There still is the issue of if presets exist during ota upgrade it
will brick the board.

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

srg74, 2021-08-04:
I will dig further. Hopefully there is explanation to this issue.

srg74, 2021-09-16:
Have been fixed.

Closed 2021-09-16.

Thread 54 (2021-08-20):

Firmware and D2 Problem

Leon751, 2021-08-20:
Hi there,
thank you for your great work.
I assembled your board V2.1.
It works but i have some problems with it.

1. I downloaded and installed your firmware.
The firmware sound_reactive : SR_shield_esp32_display_dallas.bin and : SR_shield_esp32_display_no_dallas.bin
is not working fine.
It stutters every few seconds.
The firmware SR_esp32dev.bin  run without problems.
i have installed the temperature sensor dallas too so it is not usable.

2. The next problem is when I connect another LED strip to D2 and configure it, then white dots flicker  sometimes.
I think that's too much for the EPS32.
I built 2 lamps with 230LED WS2815 each. That will be a little too much for the ESP32 or not?
The system runs very well without D2.
I have now connected both lamps to D1 and that works without any problems, but only synchronously

3. For what is the relay? If I switch the LED on or off, they do it before the relay switches. The relay switches with a delay, then the LEDs are already on.

Excuse my english. I used a translator to help.

Greetings Erwin W.

srg74, 2021-08-20:
Thank you for good words.
1) Regarding Dallas sensor. I have to check firmware. Maybe there’s a new bug introduced.
2) D2 output is configurable you have solder jumper IO1-IO3. Means I one position you choose GPIO1 as out and second is GPIO3. Try to switch outputs. Quantity of LEDs is ok to drive.
3) I don’t see how you connect your LEDs but relay cutting of power to strip. Yes it’s working with a delay for a reason.
You don’t have to apologize for your language. Our community is international and it’s expected.

Leon751, 2021-09-01:
Hi there,
I've tried a few things.
Now I also have an oled display on it.
The relay works.
Solder jumper IO1-IO3 was set.
It's OK
I haven't tried D2 any more.
The firmware runs without an oled display.
The firmware with OLED display and dallas sensor has errors.
It appears in the app
"TypeError: Cannot read property` min´ of undefined.
No segments can be defined either.
And the led stutter.
Alexa is not activated in all firmwares that I have tried.
Can't you provide the source code for download so that Alexa or IR can be activated?

srg74, 2021-09-01:
It's a lot of questions to answer at once. If you want to troubleshoot please visit WLED Discord channel. I will be there and gladly help you.

Leon751, 2021-09-02:
I am sorry for all of these questions.
I have one request, can you change the version of the mini_shield and upload as bin?
This runs very well and the display is already activated.

wemos_shield_mini_esp32_display_and_sound.bin

V0.12.0 "Kuuhaku"

Activate alexa in the weld.h folder

// # define WLED_DISABLE_ALEXA // saves 11kb

 once alexa and infrared

// # define WLED_DISABLE_ALEXA // saves 11kb
// # define WLED_DISABLE_INFRARED // there is no pin left for this on ESP8266-01, saves 12kb

Maybe all this again with the dallas temperature sensor?

That would be really nice and I hope that this version works well with alexa and more
Thank you

srg74, 2021-09-02:
Hi! You don’t have to be sorry. Reason why I ask you to join WLED Discord because it’s easier to collaborate and solve issues in real time. If question is not simple we will make a long tread and there’s a chance that issue will not be solved. V0.12 of WLED firmware is a little buggy. Better to use v0.13-b2, a lot of bug fixes was done.

Leon751, 2021-09-02:
is that this page?
https://wled.discourse.group/t/welcome-to-the-new-wled-community-should-you-post-here-or-open-an-issue/22
isn't it  only for the original wled?
I need the sound reactive wled for your board.
version V0.12. runs better than v0.13-b2

srg74, 2021-09-02:
https://discord.com/invite/KuqP7NE

Closed 2021-09-16.

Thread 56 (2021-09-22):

Shield CAD incorrect for board version 3

invalidflaw, 2021-09-22:
The version 3 of the board is 2mm larger than the CAD model provided on GrabCAD. The CAD model measures 61.27mm in length and my caliper measures my tindie purchased board at 63.24mm. It seems like the board changed size slightly.

srg74, 2021-09-22:
There is 2 SMD versions due to parts shortage. You have longer one which use bigger terminal connector and 2mm longer. All components stay in place but board outline and mounting holes is further by 2mm (on terminal connector side).

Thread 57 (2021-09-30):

Question about the solder jumpers + typo in the documentation?

nreymundo, 2021-09-30:
Hey! got a couple questions/doubts about the jumpers that need to be soldered that I can't figure out or find the right answer. Hope this is the proper place to ask but feel free to point me in a direction and RTFM :P.

```
IO15 (ESP32 only)- Let you choose if your output 15 is shifted or not (soldered left not shifted);
IO15-1 (ESP32 only) - Must be soldered if output 15 is shifted;
IO14 (ESP32 only) - Let you choose if your output 14 is shifted or not (soldered right not shifted);
IO14-1 (ESP32 only) - Must be soldered if output 14 is shifted;
```
I'm using  D1 Mini with a ESP8266 so I'm assuming I can ignore all the ESP32 only jumpers and leave them as is.

```
J-R2 - If soldered bypassing resistor R2;
```
From what I understand R2 is not needed for W8211B but no harm in using them, right? In any case is either soldering the resistor or the jumper.

```
IO1-IO3 - Let you choose D2 output, GPIO1 or GPIO3 (Feature added in shield v2.1);
```
This is the one I have no idea about. Following the pictures in the assembly guide I'm guessing I need to solder left for GPIO1 but couldn't find any documentation or don't know what to look for.

```
J-R1 - Soldered if resistor R1 must be used;
```
The FAQ section on "[Do I need R1?](https://github.com/srg74/WLED-wemos-shield/wiki/FAQ#do-i-need-r1)" mentions to solder `JP3` if using the button but I think it should be `J-R1`?.

Thanks!.

srg74, 2021-09-30:
> I'm using D1 Mini with a ESP8266 so I'm assuming I can ignore all the ESP32 only jumpers and leave them as is.
>
Yes disregard ESP32 part.
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
No need for resistor just solder jumper.
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
If you using second strip connected to terminal D2 then you have to choose one of the GPIO 3 or 1.

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
Yes it's a error left behind from previous version of the guide. Corrected for J-R1

Thank you for your post

nreymundo, 2021-09-30:
> If you using second strip connected to terminal D2 then you have to choose one of the GPIO 3 or 1.

Ah awesome!. Just so happen that I was eventually going to try to figure out how to make 2 strips work with the same shield or if that was even possible haha. Is there any documentation or anything I could read to decide which GPIO to use or would either work for a D1 Mini?.

Anyway, thanks so much for the quick reply!.

srg74, 2021-09-30:
GPIO 3 is hardware accelerated. With recent firmware version there is no problem to drive to separate strips. ESP8266 can drive from 2 pins easy. More info about firmware you can read at https://kno.wled.ge

nreymundo, 2021-09-30:
Great! Thanks for the quick help.

Closed 2021-09-30.

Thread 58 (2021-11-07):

Multi Relay setup

siedi, 2021-11-07:
Hi,

in the documentation, you mention a multi relay setup. Actually, there are pins for the power supply (5V) for a second (external) relay. But I can't find the pin to connect to the D6/GPIO12 as the internal relay is connected to.
Is that possible at all, or do I need to use one of the free external GPIOs and change the wled software?

-Siedi

srg74, 2021-11-07:
External relay board can be connected to any available exposed pin. https://github.com/srg74/WLED-wemos-shield/blob/master/resources/Images/wiki/Wemos_shield_pinout.pdf Just be aware that you need to use external relay board and not a relay only due to high current draw by relay coil.

blark, 2021-11-30:
It would be nice if you could add some documentation around using a second relay, along with a separate digital output for controlling additional pixels. Thanks.

srg74, 2021-11-30:
As I mentioned above there is pinout diagram. According to that pinout output D2/CLK could be used as second output for LEDs. Additional Relay board can be connected to any exposed pins on add-on header. Numbers of those pins on pinout diagram.

blark, 2021-12-01:
It would be very nice to have some practical examples in addition to the pinout diagram (ps. I purchased two of your boards from Tindie - great work).

I have designed and manufactured my own boards with ESP32s on them, I consider myself somewhat capable in this area... I could examine the schematic, read the data sheet for the logic level shifter, to be sure I understand things and am doing this correctly. But it would be great to have the benefit of easy hook-up instructions to save that time. Thanks for your time and effort here!

srg74, 2021-12-01:
I got your point. Need some time to figure out how to make guides understandable by most of the users.
Thanks for a comment.

blark, 2021-12-02:
Great! I was checking out the Quinled project last night and there are some decent [wiring guides there](https://quinled.info/quinled-dig-uno-wiring-guide/) that you might want to check out. Although I like your board design with the built in relay better ;)

srg74, 2021-12-14:
Closing due to no activity.

Closed 2021-12-14.

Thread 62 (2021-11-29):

Wifi connectivity problems with 12v supply

crackston, 2021-11-29:
I am not able to remain connected to WLED hotspot when it runs on 12vdc. If I keep my phone less than 6" from the ESP32 it will stay connected, but any further it will disconnect immediately. WLED is not able to connect to a wifi access point with a signal strength of 75%. If I move the jumper and operate the device on 5v only it is able to connect with no problem though walls and at least 30 feet away (I did not test greater distances).

My voltage source is a 400W Dell power supply. I have alternatively tried a 12vdc 4A plug-in switching power supply. I have two identical WLED-wemos-shields that behave exactly the same. When the board is powered with 5V and 12V (jumper removed) from the Dell PS it is able to connect and remain connected to wifi and control LED's without problem.

I tried wrapping the K78L05 in electrical tape and then aluminum foil in order to test if that is the source.  The wifi signal seems to be better and will remain connected to my phone up to 12 feet now. I still need to ground the foil to make a better shield.  Does anyone have recommendations for a better shield?

The K78L05-1000R3 is listed as a CISPR 32 Class B which is a decent EMC rating for an in-house device, so it doesn't make sense. The p-p ripple on the 5v output was less than 30mV when I tested on an oscilloscope.

Has anyone else noticed this kind of issue?

srg74, 2021-11-29:
I don't even know what to answer you. You first one who report such a problem. Buck converter shouldn't cause big interference to ESP antenna. In AP WLED is not stable but when connected to a network no issues reported.

Closed 2022-02-22.

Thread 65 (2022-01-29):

Level issues?

drapergeek, 2022-01-29:
Hi!

I ordered a shield from Tindie to try and offset some issues that I believed were based on the need for a logic level shifter. I have a d1 mini with WLED powering 3 short LED strips. The strips are mounted a couple feet from where the controller is mounted. They work great, except that if the lights are "off", when we turn on a fan or a humidifer, we end up with a few of the LEDS turning on at the beginning of the strip. As I mentioned before, my searching lead me to believe this was due to the fact that my strips were mounted away from the controller and I needed a level shifter.

I ordered and installed your board and sadly, I'm still experiencing the same issues. I made sure to wire the power in and the power out as your diagrams show. Is there something else I could be missing? Sorry for the beginner question but I'm at a lose for my next move!

srg74, 2022-01-29:
Could you please move discussion to WLED Discord?

drapergeek, 2022-01-29:
No thanks. I thought since I purchased your part, you'd be able to assist.

srg74, 2022-01-29:
You got me wrong. I did not reject you to help. Just WLED Discord allow me to collaborate about your issue in person. I'm on Discord @Serg74 waiting for you. You can DM me or talk in public.

drapergeek, 2022-01-29:
My apologies for the misunderstanding. I'll reach out in the Discord in the future. Thank you!

srg74, 2022-02-22:
solved

Closed 2022-02-22.

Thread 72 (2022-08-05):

R4 can't be 10K

wz2b, 2022-08-05:
I built 10 of these boards and they work really well.  One note that's probably a schematic/BOM error is R4 can't be 10K if you want the LED to work.  For 10 mA or so you probably want something more like 270 ohms.  For a power indicator, less current would probably be fine too - 330 would work.

srg74, 2022-08-05:
I understand  your concern. 10K is used for very dim LED.

wz2b, 2022-08-06:
Oh okay - I did not realize it was intentional.  10K with say a 3V drop
across it is 300 microamps - I'm surprised you'd be able to see that at
all.  But perhaps in a very dark room you would.

Fair enough!  Thanks for the reply.

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

wz2b, 2022-08-06:
Oh okay - I did not realize it was intentional.  10K with say a 3V drop across it is 300 microamps - I'm surprised you'd be able to see that at all.  But perhaps in a very dark room you would.

Fair enough!  Thanks for the reply.

Closed 2022-08-06.

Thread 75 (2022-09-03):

What is the relay for?

Eddiiie, 2022-09-03:
Question here, what exactly is the relay for?   I have several power supplies along the run..   Is the relay to turn on power to the power supplies before starting the LEDs (sending data)?  Allowing some time for them to come up to power, or whatever..
Sorry if I missed this in the documents somewhere.  :)

srg74, 2022-09-03:
Relay is for disconnecting power for LEDs strip. First it’s for energy saving, LEDs consuming energy when turn “off”. Plus it’s extending LEDs life time.

Eddiiie, 2022-09-03:
"Relay is for disconnecting power for LEDs strip."

So I would take the + and GND coming off the shield  and connect that to another relay that is connected to the power supplies?

srg74, 2022-09-03:
Shield can handle up to 10A. You connect power supply to shield and LEDs to output on the shield, all wires. Here is pinout https://github.com/srg74/WLED-wemos-shield/wiki/Pinout

Eddiiie, 2022-09-03:
I have 1 WLED controller, 1200+ LEDs in a single row that run on top of my fence, 4 power supplies all chained on an extension cord.   For this, I would add a 5th power supply to power the ESP32 and external relay (on all the time), run wires from LED+ and GND from the shield to power the external relay that is in turn connected to the AC to the LED power supplies?
I think this will work.

srg74, 2022-09-04:
Board is rated only 10A. If you draw more than 10A you can turn on and off secondary relays from board. All LEDs must be connected to secondary relays and fused. Or you can bypass relay and connect without relays. All depends on your setup. It’s difficult to say without knowing your setup.

Closed 2022-09-15.

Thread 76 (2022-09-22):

Could you help me on the pinout ?

Roxcreed, 2022-09-22:
Hello

First of all, thanks for your schematic and your guide
I'm having a hard time trying to find why my LEDs doesn't get neither Data nor Clock. I have a led strip with 4 wire (so 2 for power, 1 data, 1 clock). The relay is working good (I measure the output with my voltmeter, there is 5V, so no issue here). But on D1 , D2.CL I have nothing

My controler is an ESP32 from quinled. I have used this pinout : https://github.com/srg74/WLED-wemos-shield/wiki/Pinout to set mine.
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

I03-I01 has solder on the right side. With this setup my LEDs stay black. (I try to change the clock for GPIO 1 or 3 and vice versa, nothing happened)

But if I use the wire to directly touch D4 for data and TX for clock ... it works. Any idea why I don't get signal on terminals ?

srg74, 2022-09-22:
I need more details. Did you used my shield? DIY or you bought it? What is your setup? Better reach me on WLED discord.

Roxcreed, 2022-09-22:
Thanks to be still there, I was a bit worried

I use your shield 3.0 with your PCB. I order according to the BOM. I put all the bare minimum components and the components for the power jumper selector

So my ESP32 is from quinled (but the board where I plug it, is your shield 3.0). I flash according to your guide. So I use these files :
- bootloader_dio_40m.bin
- partition_4mb.bin
- WLED_0.13.3_esp32_no_mods.bin

I have a 5V power brick and my LED strip is SK9822 (similar to APA102)

How do I find you on discord ? My ID is Graw#0561

Closed 2022-09-24.

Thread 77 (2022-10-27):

D2 not working

DarthWeber, 2022-10-27:
Hi, i have just built up some of these shields - D1 works on Pin16 but i can not get D2 to work. In WLED i tried Pin1 and Pin3, but anyway Pin1 is always red and not selectable (v13.3 with Dallas / Display usermod). I tried to solder the bridge on the pcb to IO1 and IO3 - but i never get any working signal on D2/CLK.

Whats wrong ?

srg74, 2022-10-27:
If gpio1 is always red that means you have set that pin somewhere else in settings.

DarthWeber, 2022-10-27:
Sorry, got it to work. Only Pin3 is abailable - Pin1 ist blocked by anything else. I am quite sure that this was different in previous versions but maybe i am wrong.

May problem behind this was a curcuit on the solder bridge due to the change from io1 to io3

Maybe it would be senseful to mention this limitation an the layout / and or doc ?

DarthWeber, 2022-10-27:
> If gpio1 is always red that means you have set that pin somewhere else in settings.

Thats what i also thought - but it isn't defined anywhere - i checked all buttons,relay,dallas,display,....

srg74, 2022-10-27:
I will check firmware. Let’s see what happens.

DarthWeber, 2022-10-27:
Great. Pls check the one with Esp32 Dallas display. Display is disabled. -------- Originalnachricht --------Betreff: Re: [srg74/WLED-wemos-shield] D2 not working (Issue #77)Von: srg74 An: srg74/WLED-wemos-shield Cc: DarthWeber ,Author

I will check firmware. Let’s see what happens.

—Reply to this email directly, view it on GitHub, or unsubscribe.You are receiving this because you authored the thread.Message ID: ***@***.***>

[

{

***@***.***": "http://schema.org",

***@***.***": "EmailMessage",

"potentialAction": {

***@***.***": "ViewAction",

"target": "https://github.com/srg74/WLED-wemos-shield/issues/77#issuecomment-1293440227",

"url": "https://github.com/srg74/WLED-wemos-shield/issues/77#issuecomment-1293440227",

"name": "View Issue"

},

"description": "View this Issue on GitHub",

"publisher": {

***@***.***": "Organization",

"name": "GitHub",

"url": "https://github.com"

}

}

]

srg74, 2022-10-27:
Some of the the esp32 boards manufacturers swapping pins. So most likely it’s a hardware.

Closed 2022-11-05.

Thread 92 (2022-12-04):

Add the ethernet usermod to the autobuild

joggs, 2022-12-04:
Feature request.
Hi!
As many are using the quinleds with built in ethernet now, would it be possible for you to add the ethernet usermod to the autobuild to at least the esp32 max version, eg:  WLEDMM_0.14.x.x_esp32_16MB_max.bin ?
A big thank you for these auto builds!

ewoudwijma, 2022-12-04:
Hi Joggs,

Do you also need -D QUINLED_AN_PENTA in that build?
And -D WLED_USE_ETHERNET?

Best is if you provide a platformio environment you are using now.

And my plan was already to provide setups for quinled boards where all pins are pre-configured. Is that in your platformio environment?
If not, can you provide how pins are used for ethernet, microphone, 4 line display, led gpio's and what not.

joggs, 2022-12-04:
Thanks for your quick response!
For me, i think -D WLED_USE_ETHERNET is enough as I do not use the penta.
Actually I am not familiar with platformio yet, so I have to google that and learn a bit more before I can answer. When it comes to quinled, there are a couple of different esp32 hats you can buy with different types of extra hardware , so I think the creator of quinled, @quindor, could give a better answer than me. as there are different revisions etc.
For my mic setup, I am using a separate I2S mic connected to
Pin I2S Serial Data: 12
Pin I2S L/R Clock: 2
Pin I2S Serial Clock: 32
I earlier used the quinled esp32 hat that have built in mic, which I think use the same ports as above.
Also, there are different ports for different hw revisions I think. Pinout for the quad you can find here: https://quinled.info/quinled-dig-quad-pinout-guide/

srg74, 2022-12-04:
I uploaded bin file https://github.com/srg74/WLED-wemos-shield/blob/master/resources/experimental/Firmware/AudioReactive/WLEDMM_0.14.0.8_wemos_shield_esp32_16MB_max_eth.bin but you have to reconfigure pins for your board.

joggs, 2022-12-05:
Thank you!
I can now see and modify the ethernet type under wifi-settings, however, if
you have selected a module in the ethernet-type, I think that the expected
behavior is that  the wifi connection/module should be disabled, but the
wifi connection is still active and the ethernet connection is not
activated. I suppose this is something that has to be fixed in the source
code and out of this scope?

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

--

/Jörgen Bergström

intermittech, 2022-12-05:
@joggs as long as you are using a QuinLED-ESP32-ABE (Ethernet) those pins and configuration values will always be the same, no matter what board you put it on. That board might however require configuration such as for the [Dig-Uno](https://quinled.info/quinled-dig-uno-pinout-guide/), [Dig-Quad](https://quinled.info/quinled-dig-quad-pinout-guide/) or the [An-Penta](https://quinled.info/quinled-an-penta-diy-pinout-guide/) that was mentioned.

joggs, 2022-12-10:
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

Yes, the lan worked well with the ordinary WLED release and I used it for some months, but with this build I select the correct lan interface just as I usually do, but the lan does not work after I do this, so there must be something in the backend that is not working for the quinled quad lan option

ewoudwijma, 2022-12-10:
What do you mean with ordinary WLED? WLED 0.13 or latest dev (0.14 beta)?

joggs, 2022-12-10:
Sorry, I meant 0.13. With that release. I just install it, connect with
wifi and sets the quinled lan option and reboots and I have wired
connection.
With this build I do not have a working wired connection after reboot.

lör 10 dec. 2022 kl. 20:55 skrev Ewoud ***@***.***>:

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
--

/Jörgen Bergström

ewoudwijma, 2022-12-10:
Okay, try the 0.14 beta Ethernet bin which you can find here:

https://github.com/srg74/WLED-wemos-shield/tree/master/resources/experimental/Firmware

If this is also problematic you could ask for help win WLED net-testing channel on discord

joggs, 2022-12-11:
Yes, the beta works as expected:
(
https://github.com/srg74/WLED-wemos-shield/blob/master/resources/experimental/Firmware/WLED_0.14.0-b0_ESP32_ethernet_usermod.bin
)

But not the audio reactive build, which is the one I would like to use:
(
https://github.com/srg74/WLED-wemos-shield/blob/master/resources/experimental/Firmware/AudioReactive/WLEDMM_0.14.0.10_esp32_16MB_max_eth.bin
)

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

--

/Jörgen Bergström

ewoudwijma, 2022-12-11:
@srg74 , are the plaformio environment settings exactly the same in above both bins?
As I think there is no difference in Ethernet implementation in WLED AC and WLED MM...

joggs, 2022-12-11:
Update:
I kept the config and presets when flashing between the audio reactive build, to the ethernet build you wanted me to try out and I also kept the config when I flashed back to the audio rective build again, and after that, the ethernet still works on the audio reactive build.

I then just had to try to set the lan to none, to see what happens. The wifi was enabled as expected. I then set LAN to quinled-esp32 again, but then the LAN was not enabled, I was still on wifi.
I haven't played around with power cycling of  the unit up until now as I never had to do this, but now I tried that, and then after bootup, the LAN was enabled. I did not have to do this with the beta.  With the beta, it was enough with the automatic restart that occurs after you change the LAN device and save.
Not sure what you can make of this, but hope it helps.

Closed 2022-12-10.

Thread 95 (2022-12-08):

WLED not booting after having no power for a while

DopeCoder01, 2022-12-08:
Hi, I have been having an issue with the shield. I already posted the issue on the WLED discord but didn't get any useful help there.
I'm using the 3.0 board, with an ESP32 (this one to be exact: https://nl.aliexpress.com/item/32858054775.html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, with a CP2104 module).

The problem I have is reliable and repeats itself every time I do this:
1. insert the ESP32, turn on the PSU;
2. everything works as it should: WLED boots, the relay is turned on and the LEDS light up;
3. When I turn off the power, but turn it on again reasonably fast (within a minute or 2) it works like normal again;
4. But, when I turn off the power for longer than a certain period of time (which I haven't determined yet), and turn it on again, WLED refuses to boot. Power is provided to the ESP, as the onboard red LED is lit up;
5. Nothing I do can restore this. Except most of the time, when I simply remove the ESP from the headers and reinstall it, it works again.
6. Doing all of this with an ESP8266 poses no problems at all.

I have read several other problems regarding WLED not booting, which were due to some strapping pins preventing the boot of WLED. However, in those cases WLED couldn't boot at all, while in my case it does boot reliably at the start.

P.S.
I'm posting this here, because I think this problem is related closely to the hardware configuration. I hope that I'm in the right place.

srg74, 2022-12-08:
I understand your frustration. Design is exist for more than a year and if your esp32 is ok everything should work. Most likely your problem in ESP32 board.

DopeCoder01, 2022-12-08:
Okay, something I already kind of expected, but it's good to hear from someone who has a better understanding of it than me. Thank you!

Closed 2022-12-08.

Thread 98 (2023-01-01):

Pinout for VXO7805-1000 is not the same as VXO7805-500

seganku, 2023-01-01:
https://github.com/srg74/WLED-wemos-shield/wiki/Options says:
"⚠️ IMPORTANT: If you connect Additional devices to shield, 5V buck converter PS1 must be replaced with more powerful. VXO7805-1000 (Digikey p/n: 102-4258-ND) ⚠️"

The pinout for the VXO7805-1000 ([datasheet](https://www.cui.com/product/resource/vxo78-1000.pdf)) is reversed from that of the VXO7805-500 ([datasheet](https://www.cui.com/product/resource/vxo78-500.pdf)).  The board design does not have space for the VXO7805-1000, unless the pins are moved to the other side of the component (which proved annoyingly resilient to solder wick).

srg74, 2023-01-01:
You absolutely correct.

Closed 2023-01-22.

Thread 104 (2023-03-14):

WS2815 12V strip

malinin24, 2023-03-14:
How it work with 12V led strip like WS2815?
WS2815 need 12V logic level on Din.

srg74, 2023-03-14:
Logic levels for outputs is TTL (5V). Power for 12V strip is 12V but logic is still 5V.

malinin24, 2023-03-17:
I bought a 2815 LED strip on aliexpress. It does not work from 5 volts of logic. Judging by the wiring diagram of the LEDs, the VCC output is connected directly to 12 volts. When the 12 volt logic level is applied, the LEDs will light up. While I don’t have a normal 5 volt to 12 volt logic level converter, I can’t fully check the tape.

srg74, 2023-03-17:
On shield level shifter providing all necessary signal levels. You feeding to a shield 12 VDC and you have to move jumper to 12v position. LEDs strip WS2815 power wires to power out from shield and data signal to strip markings DI. Also on strip BI wire must be connected with GND. This setup must work without any problems.

Closed 2023-04-03.

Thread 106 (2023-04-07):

ESP32 D1 Mini working, no power on output terminal connectors

timmgleason, 2023-04-07:
Going to start simple, as this is the most complex assembly I have yet attempted.
Ordered PCBs, ordered parts (LCSC, Digikey, and on hand), using AITRIP D1 Mini ESP32, have Tindie 16MB version on hand once I get things working.
Passed power check, as per wiki Check page. D1 Mini powers up, flashed bootloader, 4mb partitions, and firmware. That all works fine installed into wemos shield board. Can connect and configure.
Have SK6812 and a WS2812 test strips on hand.
Cannot get either of them to light up after configuring WLED for either/or. Testing shows zero volts on G and + for X1/X2 output terminals, which indicates a problem somewhere between D1 and output terminals.

I'm looking for suggestions as to where to start looking first and what other information might be needed to answer that question (pics, jumpers soldered, etc).

Thanks,
Timm

rstarkey, 2023-04-07:
I just built a couple controllers myself and went through this.  Does the relay click when you power it on?  If not, make sure you have the correct relay GPIO configured in WLED.  It should be 19.

timmgleason, 2023-04-08:
Checking that now. I somehow missed that in all the pages of information....

timmgleason, 2023-04-08:
Nope, no relay click.
I have had the SK6812 lights working on a raw D1 mini using 0.14.0-b1 before, but they do not control especially well near the end of the run. That's why I thought using the wemos shield would be a better option (more power, more options, etc).

rstarkey, 2023-04-08:
Yeah, so go into LED Settings in WLED and enter in the correct GPIO pin for the relay. Save it and reboot.  It should make it come to life.

As for running the strip, depending on how long the strip is, you still may need to do power injection.

timmgleason, 2023-04-08:
Yes, did that (full power removal reboot). Still nothing from the relay. Assuming we are both referring to the Songle SRD (K1).
Power light on D1 mini, power light on Wemos board.
Using a 10A 5V power supply. Light string I was working with is only 99 lights and works fine with its' original 1.2A power supply, but that controller just does not provide good options.
I am now worried that some component I installed is damaged or some such. Still a relative novice with electronics beyond a breakout board.

rstarkey, 2023-04-08:
Ok, so the ESP32 gets power, so that's good.  We know the power in and fuse is good.  Now you just need to break the problem down into small pieces and test each bit.

Check your soldering work.  Make sure you don't have any bridges, open joints, missed spots, and/or shorts.

Then I'd use a multimeter to check:
* both sides of each diode to make sure you see voltage.  If you don't, it's reversed.
* Double check to make sure you didn't miss any components (I forgot a cap on one of my boards)
* probe all over the various GND pins across the board, make sure you don't have any shorts.

Refer to the schematic for an idea of how things are connected and work your way through testing each part:
https://github.com/srg74/WLED-wemos-shield/blob/master/resources/Images/schematic.pdf

If you have them, you can use dupont wires to connect the ESP to the shield, then you can jumper GPIO pins to the board and selectively test as you go.  Jumping IO19 (relay) to 3.3v *should* make it click, for example.  If it doesn't, then something might not be right with the 2N7000 or it's connections. Then probe past it and make sure you're seeing 5v to the relay. So on and so forth.

Good luck!

srg74, 2023-04-08:
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

If you want quick resolution of you issue please ring me in WLED discord @serg74#5959

timmgleason, 2023-04-08:
Solved. I had not set my pins properly in WLED for my D1 mini board.
Using this board (https://www.amazon.com/gp/product/B08L79192D) AITRIP D1 Mini, setting are as follows:
LED Pin 16, Relay pin 19, Button pin 17.
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

srg74, 2023-04-08:
Thank you for posting your solution.

drewmoseley, 2023-06-03:
FWIW, these GPIO settings worked for me on this device: https://www.amazon.com/dp/B09C5RDZ8G?psc=1&ref=ppx_yo2ov_dt_b_product_details.

Now to figure out the Mic settings.

Closed 2023-04-08.

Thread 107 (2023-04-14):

Can't connect to ESP32 while it's on the shield

Kickm3, 2023-04-14:
Hi, and thanks for your work.

I ordered a bunch of v3 boards and parts. I've put two of them together, one with lots of options and one bare minimum.

What works: The pre-check tests are all OK. When I plug the ESP32 with usb (no shield), it turns on and connects to the wifi. When I use the same board on the shields, the power led is on both on the ESP32 and the shield (not the bare minimum of course because it doesn't have one).

What doesn't work: When plugged in the shield, the ESP32 doesn't connect to wifi (neither the configured network nor in AP mode). The relay makes no sound, the + output for the leds is not powered. I've tried the reset button on the ESP32, doesn't help.

I've tried several 0.14 firmwares (some stock and some compiled myself), different wifi and pin settings... I can't think of anything else to try. Any suggestion?

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

srg74, 2023-04-14:
That is sufficient. Please move this discussion to WLED discord. I canceled answer there in more efficient way.

Kickm3, 2023-04-17:
Quick recap of our chat:

I flashing a no-mod firmware after erasing flash memory: no change.
I soldered breadboard cables to TX and RX, and used a ground pin to plug a USB-to-serial reader. This gave me logs at boot:

With ESP not plugged in shield:
`rst:0x1 (POWERON_RESET),boot:0x3b (SPI_FAST_FLASH_BOOT)
configsip: 0, SPIWP:0xee
clk_drv:0x00,q_drv:0x00,d_drv:0x00,cs0_drv:0x00,hd_drv:0x00,wp_drv:0x00
mode:DOUT, clock div:2
load:0x3fff0018,len:4
load:0x3fff001c,len:1044
load:0x40078000,len:10124
load:0x40080400,len:5828
entry 0x400806a8
ets Jun  8 2016 00:22:57

rst:0x10 (RTCWDT_RTC_RESET),boot:0x1b (SPI_FAST_FLASH_BOOT)
configsip: 0, SPIWP:0xee
clk_drv:0x00,q_drv:0x00,d_drv:0x00,cs0_drv:0x00,hd_drv:0x00,wp_drv:0x00
mode:DOUT, clock div:2
load:0x3fff0018,len:4
load:0x3fff001c,len:1044
load:0x40078000,len:10124
load:0x40080400,len:5828
entry 0x400806a8
�Ada`

With ESP32 plugged in shield:
`rst:0x1 (POWERON_RESET),boot:0x2b (HSPI_FLASH_BOOT)
flash read err, 1000
ets_main.c 371
ets Jun  8 2016 00:22:57

rst:0x10 (RTCWDT_RTC_RESET),boot:0x2b (HSPI_FLASH_BOOT)
flash read err, 1000
ets_main.c 371
ets Jun  8 2016 00:22:57

rst:0x10 (RTCWDT_RTC_RESET),boot:0x2b (HSPI_FLASH_BOOT)
flash read err, 1000
ets_main.c 371
ets Jun  8 2016 00:22:57

rst:0x10 (RTCWDT_RTC_RESET),boot:0xb (HSPI_FLASH_BOOT)
flash read err, 1000
ets_main.c 371
ets Jun  8 2016 00:22:57

rst:0x10 (RTCWDT_RTC_RESET),boot:0xb (HSPI_FLASH_BOOT)
flash read err, 1000
ets_main.c 371
ets Jun  8 2016 00:22:57

rst:0x10 (RTCWDT_RTC_RESET),boot:0x3 (DOWNLOAD_BOOT(UART0/UART1/SDIO_REI_REO_V2))
waiting for download`

So when put on shield, the board starts in download mode, waiting for a firmware upload, as if I pushed the (nonexistent) BOOT button.

On these ESP32, the GPIO0 pin is used as the BOOT button: when LOW it's pushed, when HIGH (3.3V) it's not. Usually it's HIGH by default (using built-in resistors), and for some reason it stayed LOW (<1V) on mine. So I soldered a wire from 3.3V to GPIO0 on the shield and bam, problem solved.

I'll try with another brand of ESP32 to see if this one is problematic, and update here.

Serg, thanks again for your help troubleshooting.

srg74, 2023-04-17:
Better not to do with direct connection to 3V rail but with pull up resistor 4.7k

petr-stupka, 2024-05-21:
I found out that if i'll cut the pins like on the [picture](https://github.com/srg74/WLED-wemos-shield/raw/master/resources/Images/wiki/placement2.jpg) so 1x8,1x10 and 2x8, then i do not have such problem.

If i use ESP32 with 2x10 on both sides, i got the same problem.

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

Now clue why it is so, i'm just beginner :)

srg74, 2024-05-21:
Thanks. I’ll check if this is related to those pins

spad, 2024-12-04:
I have the same issue with Wemos D1 ESP32. On the same pcb, using d1 mini everithing is fine (of course with the proper pin configuration changes).
The ESP32 works fine when out of the board. When plugged there is no wifi, power led is very low in light. No relay "click". The push button lights the D1 led output (random colors) but pressing it again does not power them off.

srg74, 2024-12-04:
Most likely you have esp board with slightly different pinout than usual.

spad, 2024-12-04:
No, I've checked. It seems the problem is my board cannot be powered by Vcc pin, only by usbc port

srg74, 2024-12-04:
There is a diode between usb port and VCC pin. Short that diode and see if you have power

spad, 2024-12-05:
Thanks srg74. Me too I found this fix on expressif github repo (https://github.com/espressif/arduino-esp32/issues/1972). Unfortunately it looks like my board has some other issue than the diode. As far I can see in my board there is a resistor above the diode not present in the board of that post.
I wonder if there is a store where we can buy the wemos esp32 without this hw bug.

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

Closed 2023-05-05.

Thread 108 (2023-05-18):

Standard build of the esp32 firmware without any fancy add-on or shield?

DwaineGarden, 2023-05-18:
There use to be a esp32 build without any fancy add-ons or shields.     I can't tell which one is for a simple ESP32. with no options.

https://github.com/srg74/WLED-wemos-shield/tree/master/resources/Firmware/%40Aircoookie/v0.14.0-b2

srg74, 2023-05-19:
No options, just update pins regarding your setup : https://github.com/srg74/WLED-wemos-shield/blob/master/resources/Firmware/%40Aircoookie/v0.14.0-b2/mini_shield/WLED_0.14.0-b2_esp32_mini_shield_minimum_4mb.bin

DwaineGarden, 2023-05-19:
ok thanks.....

Morcegolas, 2023-05-25:
> No options, just update pins regarding your setup : https://github.com/srg74/WLED-wemos-shield/blob/master/resources/Firmware/%40Aircoookie/v0.14.0-b2/mini_shield/WLED_0.14.0-b2_esp32_mini_shield_minimum_4mb.bin

Hello, first of all thanks for sharing this project with others.

I build one board for now but have material for build more, I'm trying to put this one to work first and then I will build the others for the LEDs I want to use in my house.

I'm using this cheap board for now but I might buy another now that I saw your recommendations
[€ 1,39  17％ Off | D1 Mini ESP8266 ESP-12 ESP-12F CH340G V2 USB WeMos D1 Mini WIFI Development Board D1 Mini NodeMCU Lua IOT Board 3.3V With Pins
https://a.aliexpress.com/_mM3XQv2](D1 Mini v4.0.0)

I have many questions, but my first two are:
 - Do I need to update the pins for my board? If yes how do I do that?
 - When I connect the power to the board I ear the relay opening, but when I turn the power off/on in the app/web ui I don't hear anything, is it normal?

Thanks once more for the great project.

srg74, 2023-05-26:
You have assign pins in settings. All pinouts available in wiki.

Morcegolas, 2023-05-26:
Ok it's in the led settings, but I only find 4 gpio settings:

- Led gpio
- button gpio
- IR gpio
- Relay gpio

LEDs are working, button is also working but the relay I already changed to GPIO12 inverted or not it's not making the clicking noise when I turn on/off.

Morcegolas, 2023-05-26:
I already found and changed SCL and SDA GPIOs, they are in the Usermods. But I still haven't figured out why relay isn't working. 😔

srg74, 2023-05-26:
Look for your pins in here https://github.com/srg74/WLED-wemos-shield/wiki choose your board esp8266 or esp32 and follow GPIO numbers.

Morcegolas, 2023-05-26:
I already done that, that's where I found the info, but the relay doesn't click. It has to be esp8266 board because it only goes to GPIO16.

Morcegolas, 2023-05-26:
I used an 'hf3ff 005-1zst' relay but its also 5V 10A 5Pin, and it clicks when I power up the board, I don't think the problem is there.

Morcegolas, 2023-05-26:
The only thing different that I make was flashing the firmware, I didn't found bootloader.bin only bootloader.elf. So I flashed the firmware using ESP-Flasher-dev-macOS using only the firmware file.
If I need to flash with ESPtool, bootloader, partitions file and firmware could you please 🙏🏼 show me the links of the files that I need to use?
Thanks 🙏🏼

srg74, 2023-05-26:
If you need more help please move to https://discord.gg/Qkt29cG4 my nick @Serg74#5959

Closed 2023-06-02.

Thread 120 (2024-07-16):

Plugin LEDs creates a shortcut on v3

gjornod, 2024-07-16:
After assembling and performing the appropriate checks, I power (5V) the shield successfully.
I then configure the appropriate pin to control the relay.
I can turn off and on my ESP8266 module with the push button and hear the relay working properly.
The issue starts when I add an LED strip.
If the relay is on, I can light the strip. However, if I turn off and and then on (with the push button), it immediately creates a shortcut which restarts my power supply.
The system then starts to turn on, open the relay, and then shut down because of the short circuit infinitely, until I put a jumper between the power supply of the shield and the power supply of the strip (direclty on the molex or from the solder trace).

Things I tried to figure out what was wrong:

- I have soldered two different PCBs
- I have tried on ESP8266 wemos D1 mini and one ESP32 minikit wemos (I changed the relay and button pins in the config before starting)
- I tried to change the relay multiple times, I have TE as recommended but also Tongling.
- I have used different (out of the box) strips, all WS2812B though.

Did I miss something in the configuration?
I am running out of things to try and would greatly appreciate any guidance.

srg74, 2024-07-17:
Looks like you have power supply overloaded. If you using relays listed in BOM everything should be fine.

gjornod, 2024-07-17:
I used an industrial power supply and indeed the problem is solved. Thanks for the quick answer, I indeed  forgot to try another power supply.
I have been using the power supply from the previous setup for 100+ LEDs and the same relay. Do you have any idea why for 30 LEDs here I need a more powerful power supply?
Anyway, thank you for your great contribution, this is a very nice project.

srg74, 2024-07-17:
All depends on type of LED. Very important to use reliable power supply from reputable manufacturers. Cheap power supplies very often don't produce sufficient amounts of power. The best if you visit [WLED discord](https://discord.gg/QAh7wJHrRM) channel and read posts from users who already experience similar problems. Plus you could find very nice projects there too.

Closed 2024-08-04.

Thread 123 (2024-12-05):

Relay does not switch off

spad, 2024-12-05:
My setup:
- universal shield with relay
- Wemos ESP32
- WLED 1.4.4

When I power the shield, the relay is off. Pushing the button, the relay switch to on but never switch off when the button is pressed again , nor when switching the "Power" menu in the UI. The LEDs, btw, are working as expected.

Using the board without shield, IO019 has level 0 and 3.2V when pressing the Power in the UI..
Wen mounted on the shield these levels are 0V and 2.5V

srg74, 2024-12-05:
Check in the relay settings first

spad, 2024-12-05:
I'm using v3.0 from pcbway.
I already cheked the build and the components values. All the components are from DigiKey from the BOM.
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

srg74, 2024-12-08:
Your board looks ok. Signal levels for relay are ok. Only things could be wrong is MosFET and diode.

Closed 2024-12-26.

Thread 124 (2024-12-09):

PCB Files Available?

jace055, 2024-12-09:
Hi There!

Are the files for the PCB available?  I would like to modify your (excellent) design to remove the relay and add a DC/DC converter to run the board and the lights off of a 24v power supply.  I am currently using [these ](https://www.amazon.com/dp/B01MQGMOKI?_encoding=UTF8&psc=1&ref_=cm_sw_r_cp_ud_dp_VW6ZRCTA8ZP20Y62DWXB) converters.  They are only 3A but I am only using them to run the lights on my 3d printers with your board.  My current draw is 700ma (Prusa) and 1.5a (Voron).  I would also like to add an additional mini fuse holder for the incoming power to the converter.

I've built 15 of your boards so far for use around my home!  Everything from my Terminator arm lamp (modified base to fit your board on Printables) to my Christmas lights is powered by your board.  Much thanks!

srg74, 2024-12-09:
Board actually has DC/DC converter up to 24V. Schematic is available in resources.

jace055, 2024-12-09:
I was under the impression the output of the DC/DC converter was only sent to the D1 board.  The input power and voltage would be sent to the LED strip.  Was I wrong?  I thought this option was for powering the D1 when using 12v light strips.

srg74, 2024-12-09:
Voltage supplying board the same as voltage for LED strip. On board dc/dc converter is for esp circuit.

jace055, 2024-12-09:
That's what I thought.  Thanks.

I didn't realize PCBWay paid out commissions.  Had I known that I wouldn't have asked for your PCB layout.

Thanks again!  Great board!

Closed 2024-12-09.

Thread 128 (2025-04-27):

Relay not switching

NXTler, 2025-04-27:
Greetings,
yesterday I assembled my first controller and began testing. Everything seems to work nicely so far, and I'm very impressed with overall quality. However, for reasons unknown to me, the Relay does not seem to switch at all and is permanently off. Everything is as the BOM suggests, except for SRD-05VDCSL-C (swapped with J1071CS5VDC.36) and 1N4148-P-TAP (swapped with 1N4150TR as per #97 ) with should be identical.
I checked all solder connections and component orientation so far. The only odd thing I noticed was that the mosfet's gate always had about 2.8 V (respective to ground) applied regardless of wled settings.

srg74, 2025-04-27:
Did you check pin settings for a relay?

NXTler, 2025-04-27:
Yes, the correct GPIO pin is selected, I have also checked if it's correct for my ESP and that I have continuity.

NXTler, 2025-05-13:
Are there any specific measurements that I could take to ensure that the mosfet is functional, for example?

srg74, 2025-05-13:
There is no special way to do it. Simple tutorial https://www.youtube.com/watch?v=gloikp9t2dA
Circuit I used is very common and everything should work. There is something you have overlooked.

NXTler, 2025-05-14:
Okay, so I took some measurements.
The LEDs are turned off: 0V are applied to the Gate and the difference between the Source and the Drain is 5,05V.
The LEDs are tuned on: 2,75V are applied to the Gate and the difference between the Source and the Drain is about 3,75.
When the LEDs are on, and I briefly apply 5V to the Mosfets gate, the Relay switches and stays in position until I turn off the LEDs.

What I gather from this is, that I need to somehow increase the voltage applied to the Mosfet's gate to have proper Relay switching.

Closed 2025-06-02.

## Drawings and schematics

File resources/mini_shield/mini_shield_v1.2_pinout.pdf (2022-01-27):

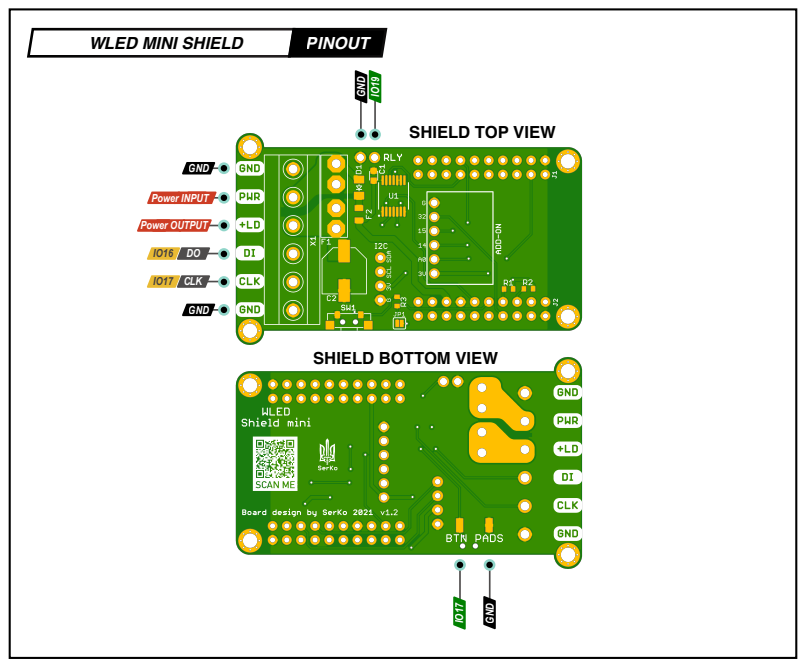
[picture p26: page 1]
GND; WLED MINI SHIELD; PINOUT; Power INPUT; Power OUTPUT; IO17 CLK

GND
SHIELD TOP VIEW

SHIELD BOTTOM VIEW

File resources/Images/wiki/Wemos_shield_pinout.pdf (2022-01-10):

UNIVERSAL WLED SHIELD | PINOUT | v3.0

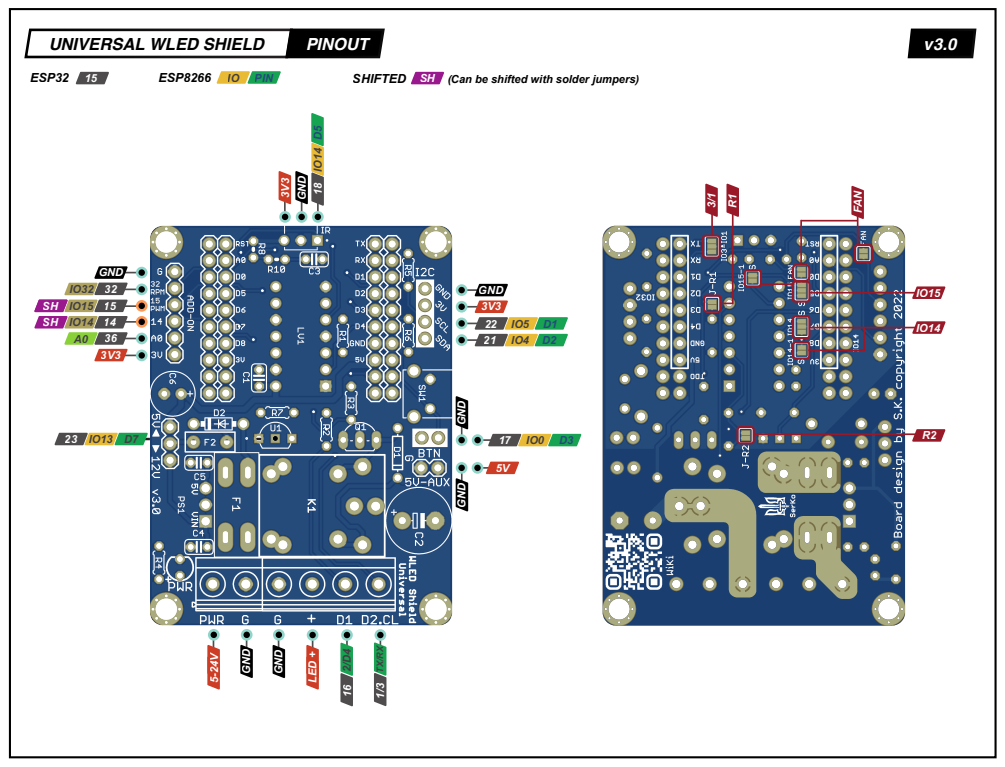
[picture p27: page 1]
ESP32 15; ESP8266 IO PIN; SHIFTED SH (Can be shifted with solder jumpers); SHSH IO14 14; GND; LED +; GND 3V3; FAN

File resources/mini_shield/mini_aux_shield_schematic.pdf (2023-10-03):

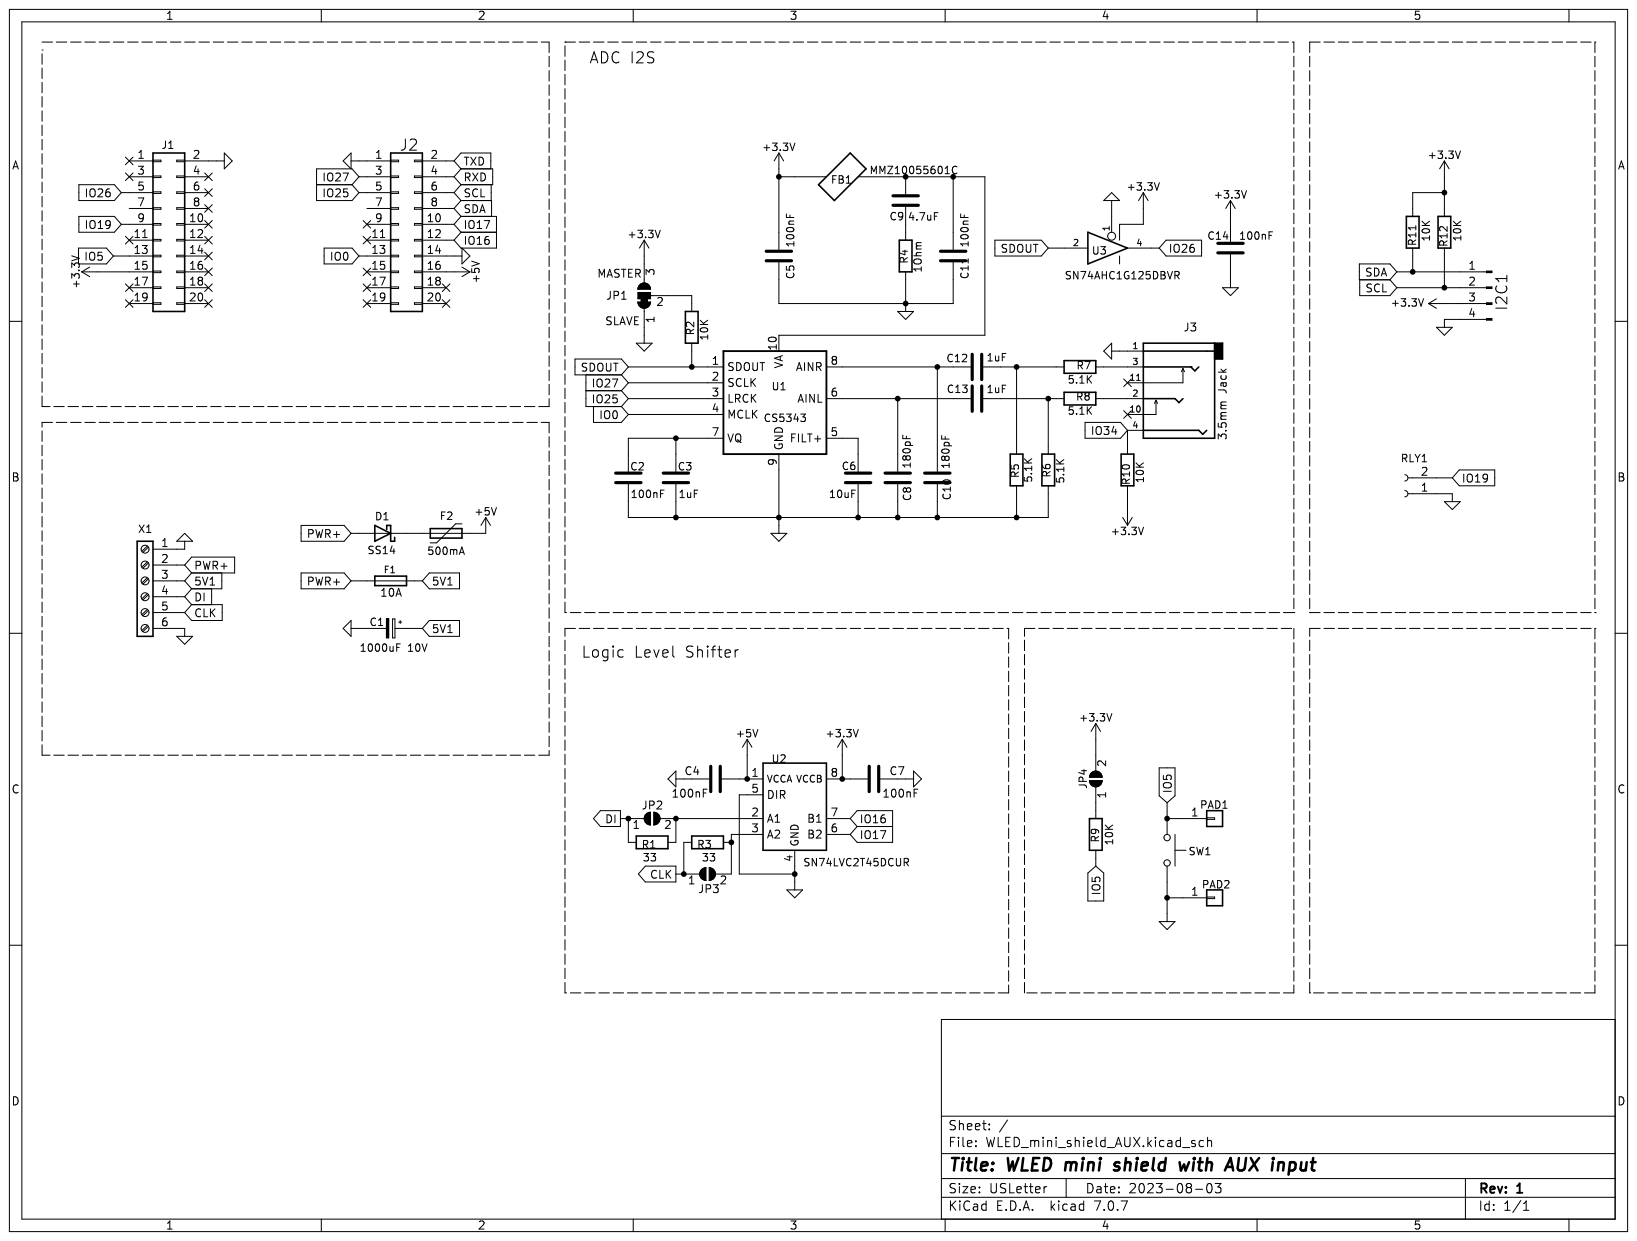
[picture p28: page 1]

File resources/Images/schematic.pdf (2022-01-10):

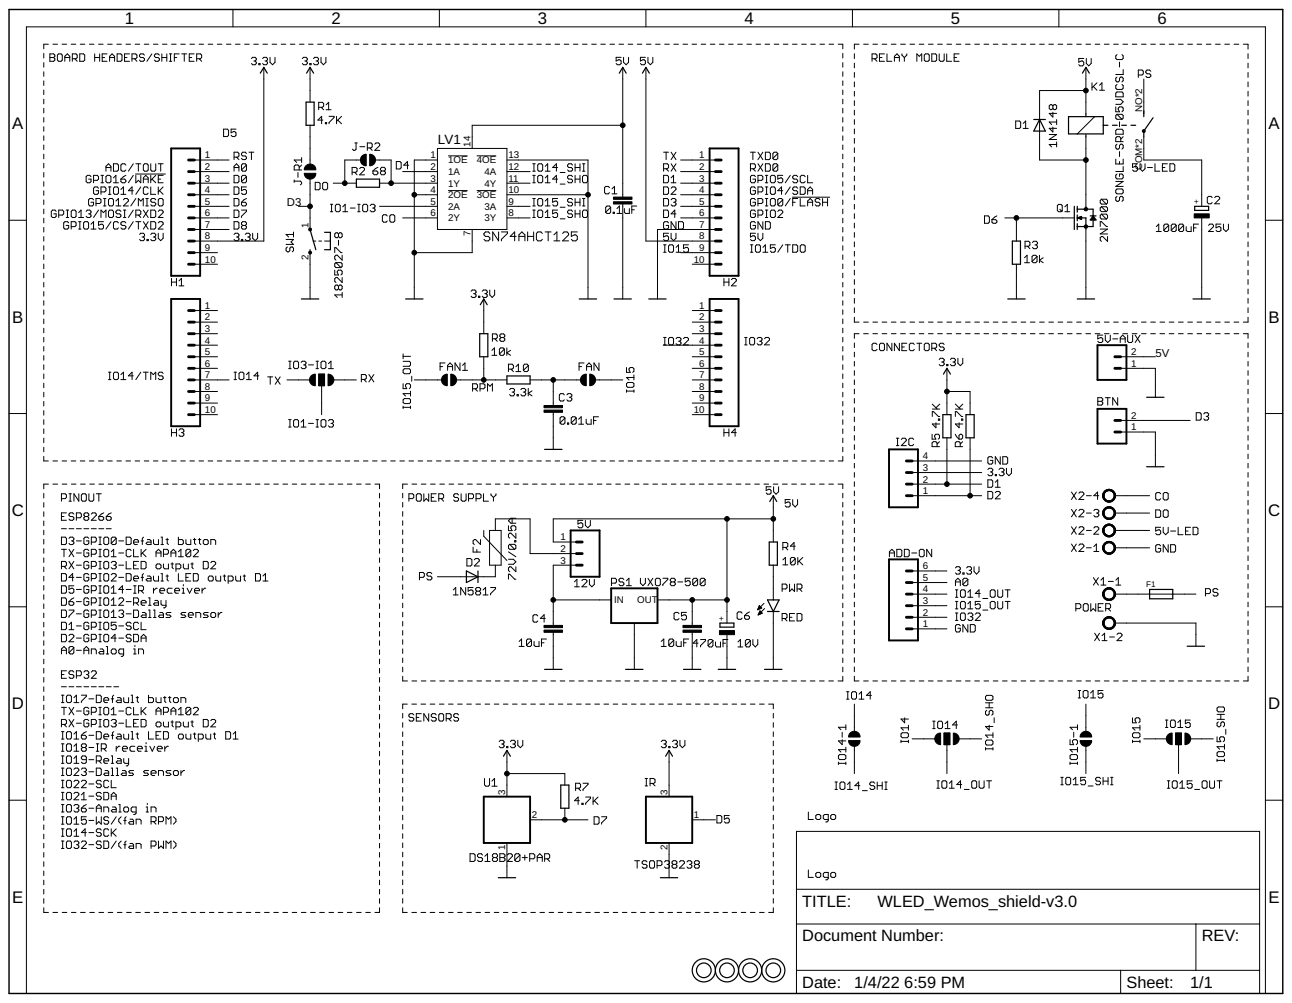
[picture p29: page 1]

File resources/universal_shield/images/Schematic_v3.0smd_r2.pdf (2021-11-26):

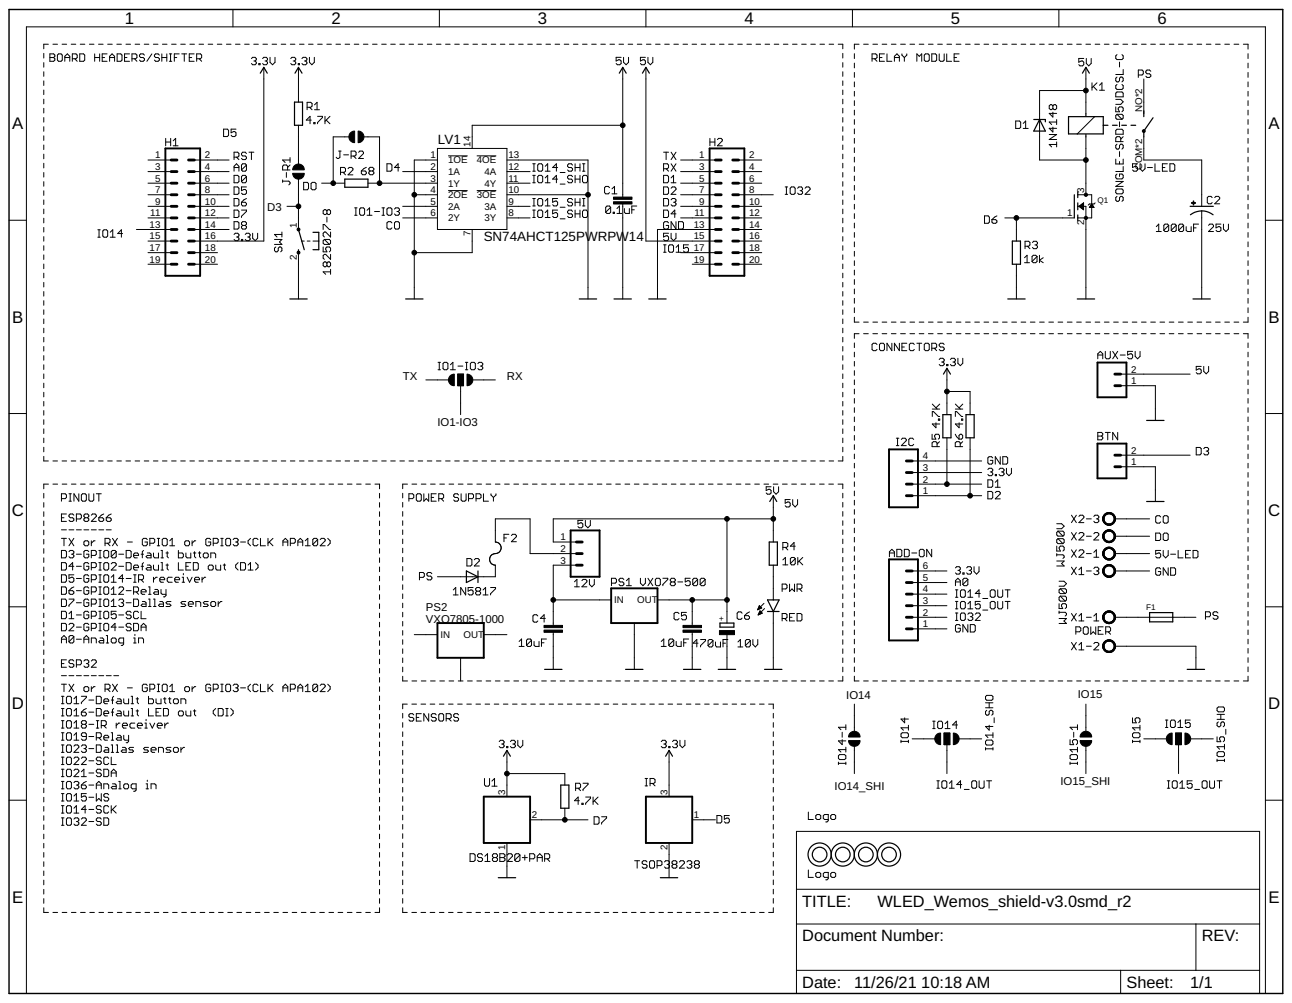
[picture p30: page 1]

Document Number: | REV:

Date: 11/26/21 10:18 AM | Sheet: 1/1

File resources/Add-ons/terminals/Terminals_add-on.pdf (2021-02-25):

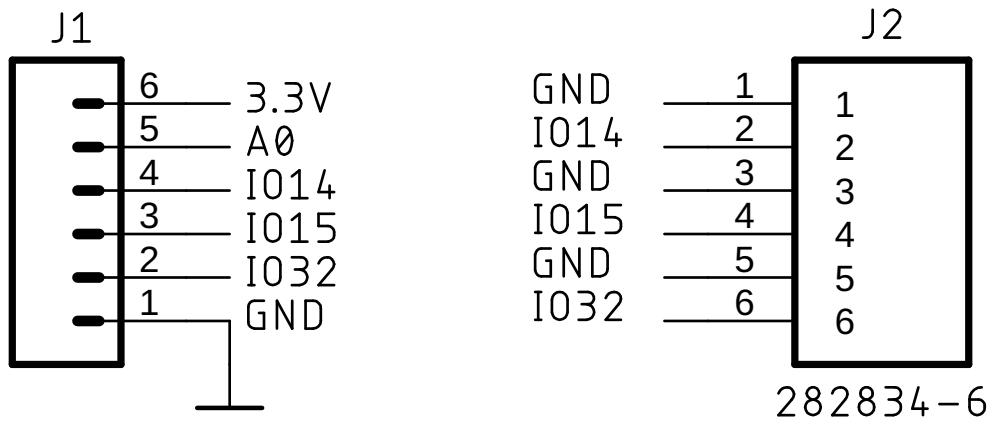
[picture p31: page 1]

Document Number: | REV:

Date: Date: 2/25/21 6:27 PM 2/25/21 6:27 PM | Sheet: Sheet: 1/1 1/1

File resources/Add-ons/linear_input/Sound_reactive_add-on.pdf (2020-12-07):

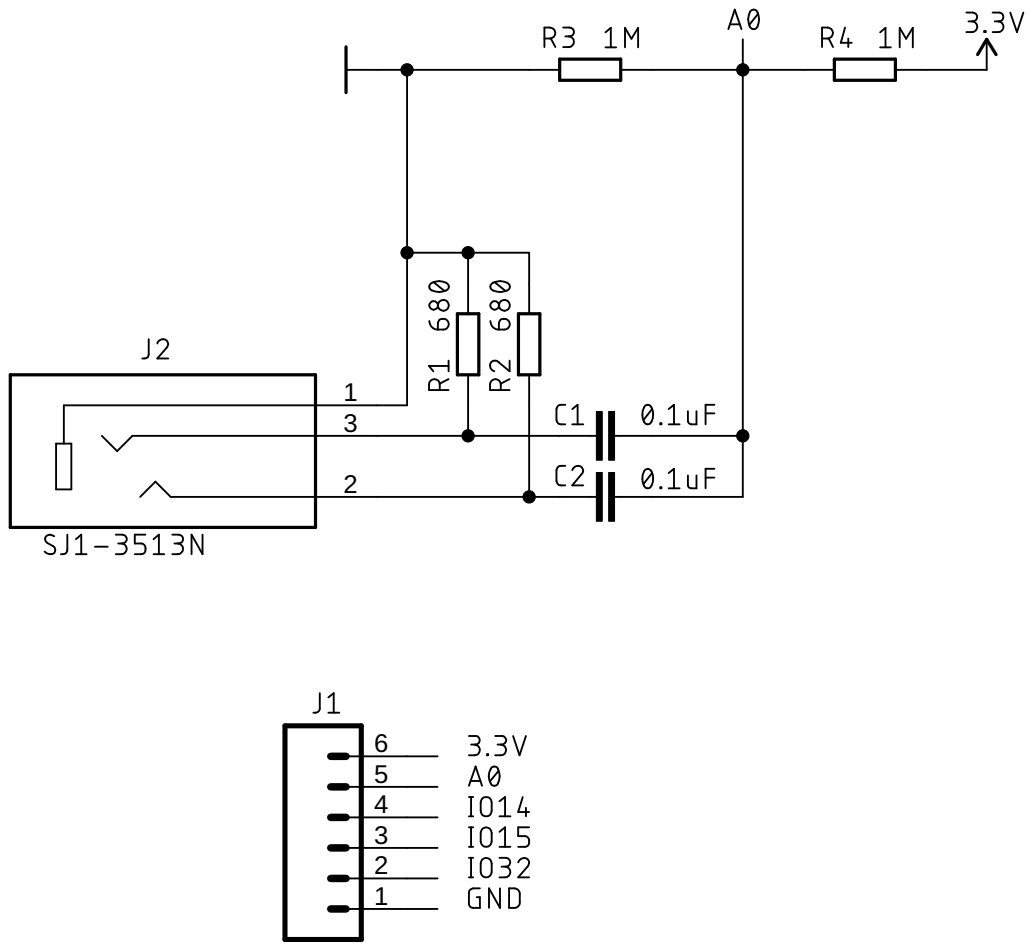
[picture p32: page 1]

Document Number: | REV:

Date: Date: 12/6/20 9:23 PM 12/6/20 9:23 PM | Sheet: Sheet: 1/1 1/1

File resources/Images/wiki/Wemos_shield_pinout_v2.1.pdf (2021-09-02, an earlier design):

15

### ESP32

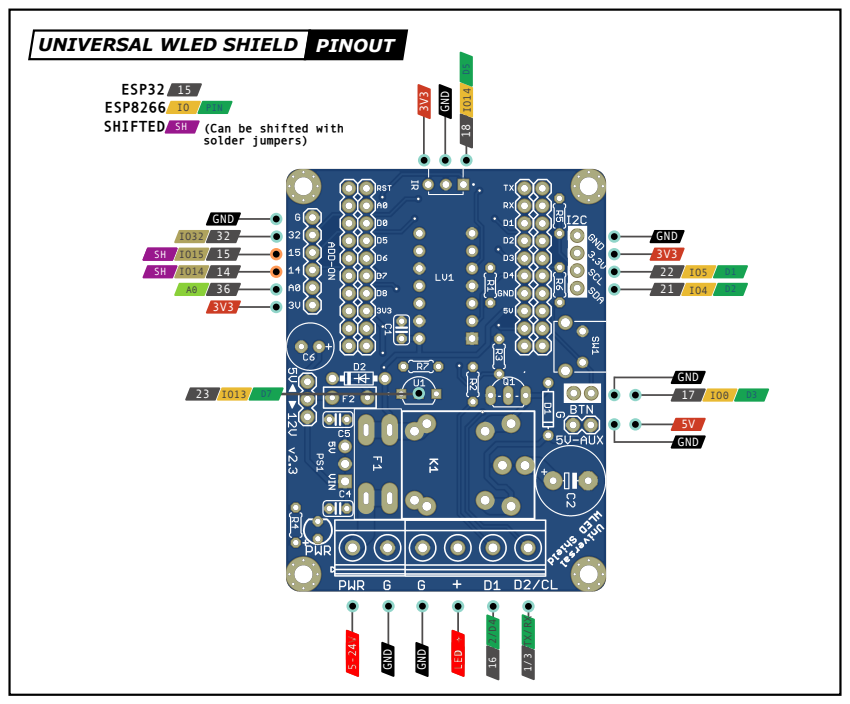
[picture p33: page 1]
GND; LED +; PIN; ESP8266; SHIFTED; (Can be shifted with; solder jumpers)

UNIVERSAL WLED SHIELD PINOUT

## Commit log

2021-05-30 new board added
2021-05-30 updated schematic
2021-07-18 Added binary @blazoncek for display and rotary encoder usermods
2021-07-21 Fixed @blazoncek firmware for rotary encoder usermod
2021-07-23 Updated @blazoncek firmware to build 2107231
    - Added esp32-pico-d4 build;
    - Added rotary encoder+display mods.
2021-08-02 Added board pic
2021-08-16 Added BOM for orders on LCSC.com
    [BOM_v2.1_LCSC.xlsx]
2021-09-02 Updated description to schematic
2021-10-03 @blazoncek firmware updated to build 2110031
    PWM fan usermod fixed.
2021-10-21 @blazoncek firmware updated to build 2110211
    Finally fixed pico-D4!
2021-10-25 @blazoncek firmware updated to build 2110251
    Usermods using relays updated
2021-10-27 Sound reactive firmware for ESP32 updated to build 2110271
2021-10-29 Sound reactive firmware for ESP32 updated to build 2110281
2021-10-31 Sound reactive firmware for ESP32 updated to build 2110311
2021-11-03 Sound reactive firmware for ESP32 updated to build 2111031
2021-11-04 Sound reactive firmware for ESP32 updated to build 2111041
2021-11-08 Sound reactive firmware for ESP32 updated to build 2111081
2021-11-12 Sound reactive firmware for ESP32 and ESP8266 updated to build 2111121
2021-11-15 Sound reactive firmware for ESP32 updated to build 2111141
2021-11-24 Update Board with OLED.jpg
2021-11-24 Create Board with OLED.jpg
2021-11-25 Re-organize structure
    [BOM.1.3.Update.xlsx, BOM_Digi-key_v2.1.csv, BOM_v2.1.xlsx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]
2021-12-01 Added binary ESP32_fan_dallas_4mb
2021-12-01 @Aircoookie firmware updated to v0.13.0-b5 build 2112010 with ESP32 core 3.4
2022-01-10 Updated BOM to v3.0
    [BOM_Digi-key_v3.0.csv]
2022-02-21 Latest test bin for 4ch board
2022-09-09 @blazoncek firmware for ESP32-S2 re-uploaded
2022-09-11 @blazoncek firmware for ESP32-S2, S3, C3
2022-09-14 @blazoncek firmware for ESP32-S2, S3, C3 build 2209131
2022-09-14 @blazoncek firmware for ESP32-S2, S3, C3 build 2209141
2022-09-16 @blazoncek firmware for ESP32-S2, S3, C3 build 2209161
2022-09-17 @blazoncek firmware for ESP32-S2, S3, C3 build 2209171
2022-10-04 @MoonModules audio reactive firmware for ESP32-C3 build 2210041
2022-10-13 Upload updated Flash Tool
    Added WLED ESP flasher. Tool for flashing bin files to ESP chip boards.
2022-11-12 Enclosure files
    [BOTTOM_V7_SR-WLED-Shield_Sergs-Board-V3_Mic_White.stl, TOP_SR-WLED_Shield_SergsBoard_Mic3-0_white.3mf]
2022-11-12 update folder
    [BOTTOM_V7_SR-WLED-Shield_Sergs-Board-V3_Mic_White.stl, TOP_SR-WLED_Shield_SergsBoard_Mic3-0_white.3mf]
2022-11-29 Updated 2 bin files.
    Small update for 16mb board and pico board
2022-12-11 PIR mod update
    ESP8266 binary
    ESP32 binary
2022-12-23 ESP32 mini board info

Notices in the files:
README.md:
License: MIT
